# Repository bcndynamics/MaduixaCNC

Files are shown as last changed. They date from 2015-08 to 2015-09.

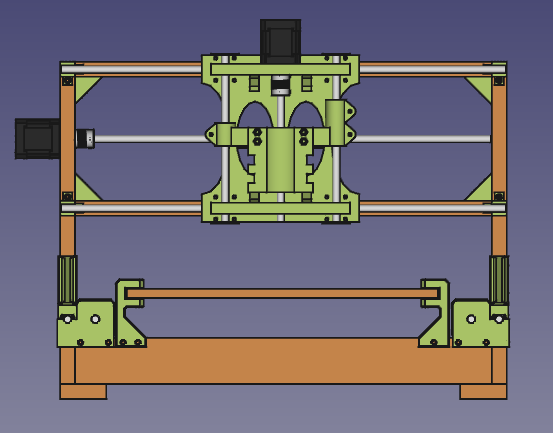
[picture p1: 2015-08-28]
03.Pictures/MaduixaCNC-front-r.png

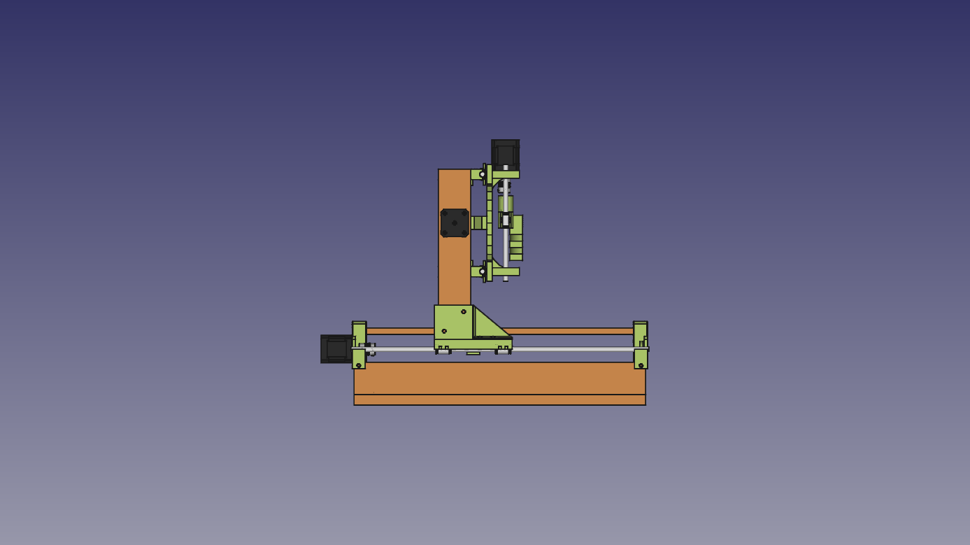
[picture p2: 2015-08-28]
03.Pictures/MaduixaCNC-left.png

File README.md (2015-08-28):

MaduixaCNC is an open source technology project developed by BCN Dynamics. It is a kit to do it yourself a CNC milling machine of 3 axis.

Components are the more accessible and affordable as possible. With accessible we mean that the components should be easy to find anywhere in the world. So, MaduixaCNC uses DM wood for the base structure and frame, 3dprintable plastic parts, and some common hardware stuff such as screws, nuts, bars, and so on. It uses NEMA17 motors and Arduino electronics.

MaduixaCNC is a CNC machine for milling, machining, drilling, PCB milling/routing, drawing and cutting, among others. Many things can be automatically produced with a CNC machine. MaduixaCNC is ready to use many possible tools, you just need to configure it your way.

It has a universal holder to use any tool. So you can plug a drill, a dremel, a cutter, a laser, a pen or whatever you need.

It is open source, published under GPL v3.0. So anyone can reproduce it wherever in the world without patents problems. Moreover, anyone can participate by providing improvements, changes or derivates. We are waiting for your improvements!

More information at BCN Dynamics website:
http://bcndynamics.com/en/product/kit-maduixa-cnc
http://bcndynamics.com

Spanish and Catalan information:
http://bcndynamics.com/es/MaduixaCNC
http://bcndynamics.com/ca/MaduixaCNC

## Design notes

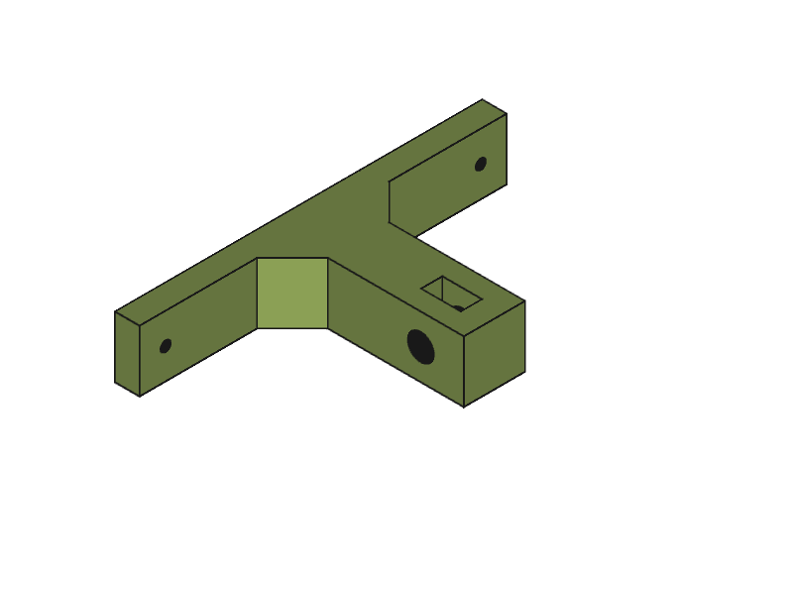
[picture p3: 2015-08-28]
03.Pictures/x-drive-train-CNC.png

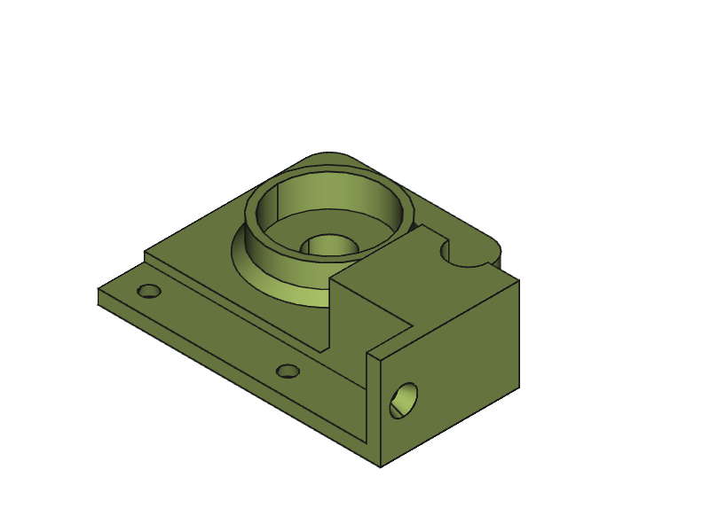
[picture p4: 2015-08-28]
03.Pictures/y-end-idler-CNC-left.png

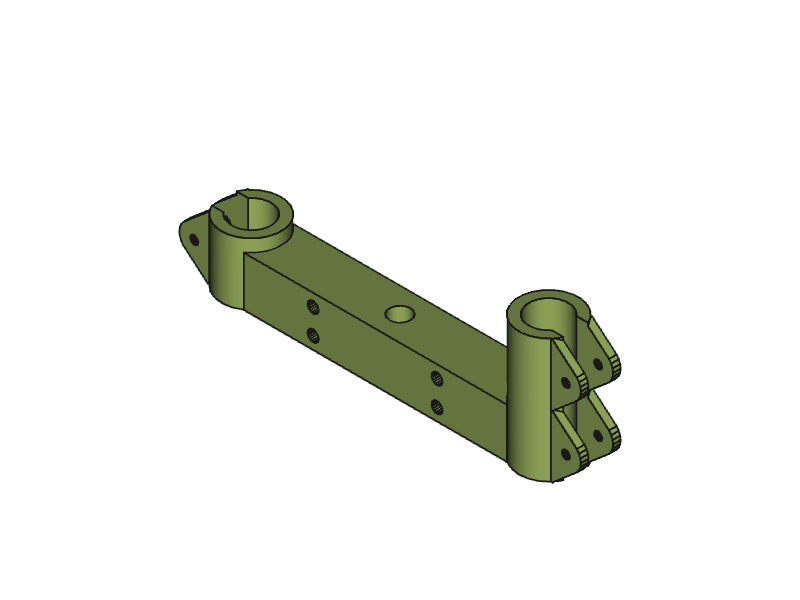
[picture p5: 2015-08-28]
03.Pictures/z-carriage-CNC.png

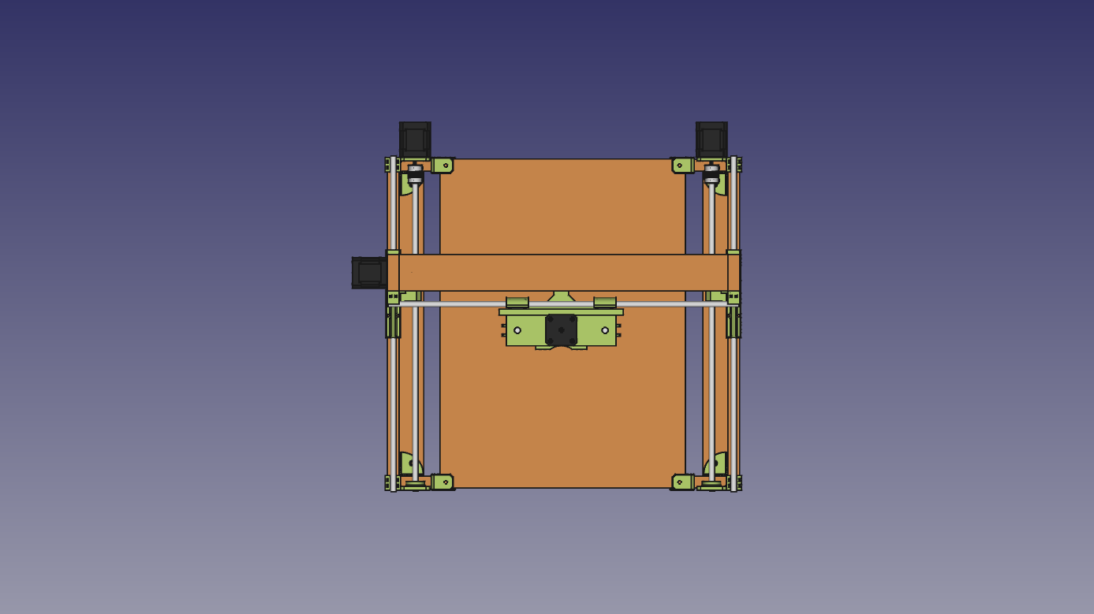
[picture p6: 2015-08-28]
03.Pictures/MaduixaCNC-top.png

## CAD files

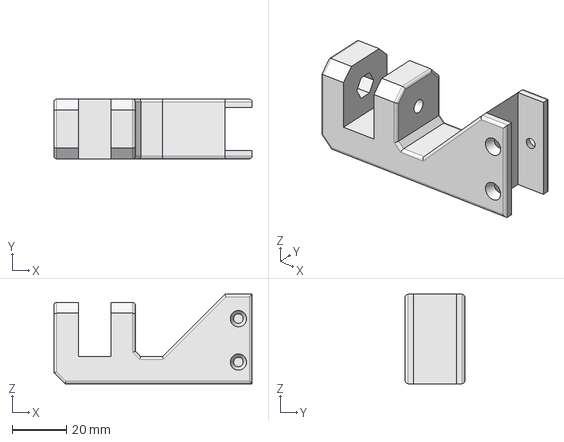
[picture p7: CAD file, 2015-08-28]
01.Sources/bed-holder-CNC.fcstd
73.0 x 22.0 x 33.0 mm

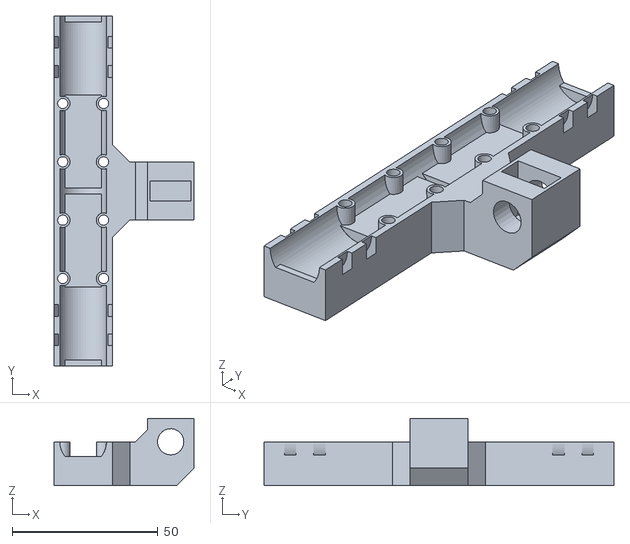
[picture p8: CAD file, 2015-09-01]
02.STLs/y-carriage-CNC.stl
48.0 x 120.0 x 23.0

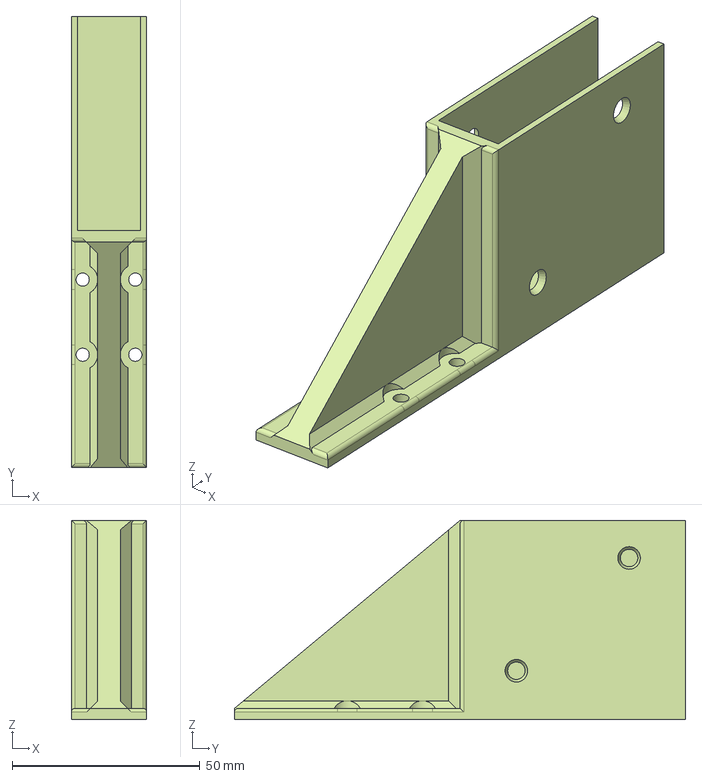
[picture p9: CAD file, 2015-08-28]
01.Sources/y-triangles.fcstd
20.0 x 120.0 x 53.0 mm

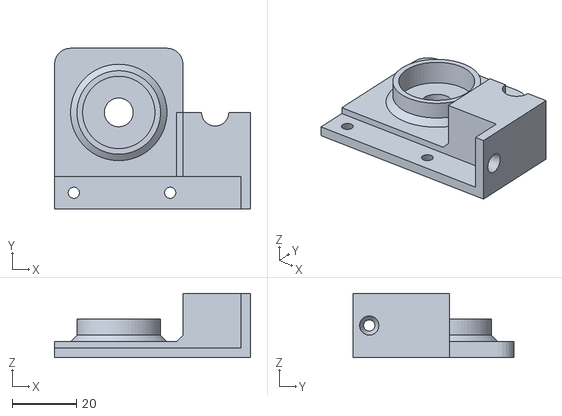
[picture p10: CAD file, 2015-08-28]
02.STLs/y-end-idler-CNC-right.stl
61.0 x 50.0 x 20.0

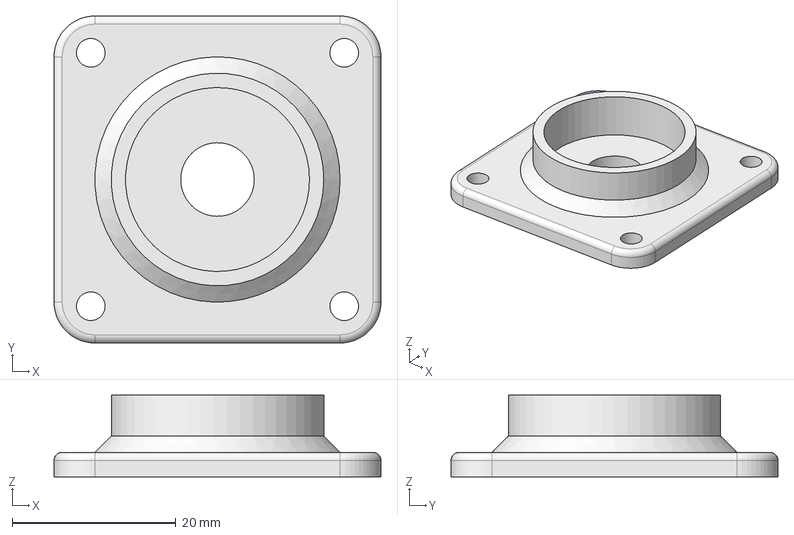
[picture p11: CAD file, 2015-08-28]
01.Sources/x-end-idler-CNC.fcstd
40.0 x 40.0 x 10.0 mm

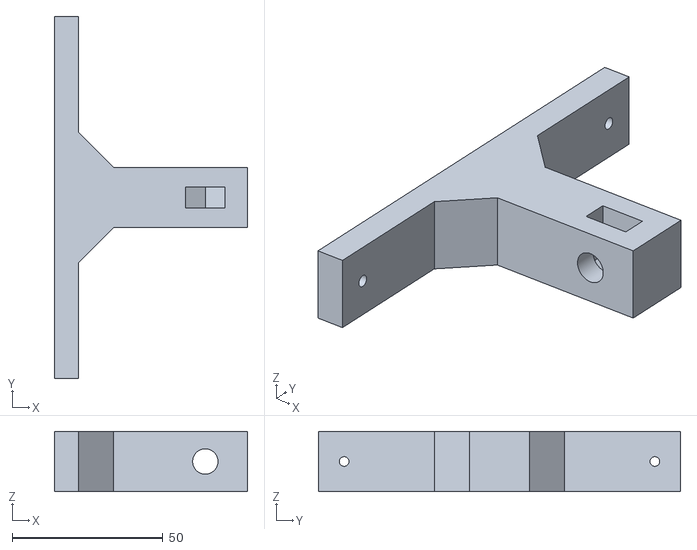
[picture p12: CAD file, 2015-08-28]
02.STLs/x-drive-train-CNC.stl
64.0 x 120.0 x 20.0

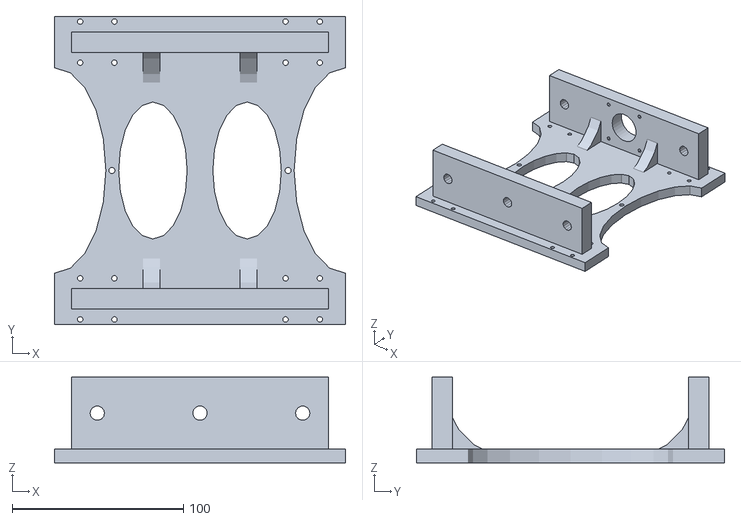
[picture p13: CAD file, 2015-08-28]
02.STLs/x-carriage-CNC.stl
170.0 x 180.0 x 50.0

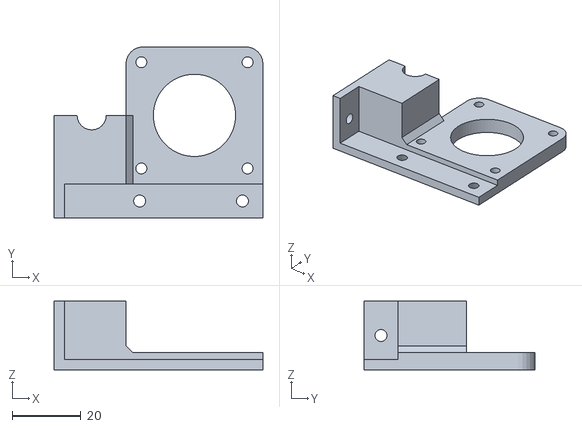
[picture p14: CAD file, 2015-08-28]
02.STLs/y-end-motor-CNC-right.stl
61.0 x 50.0 x 20.0

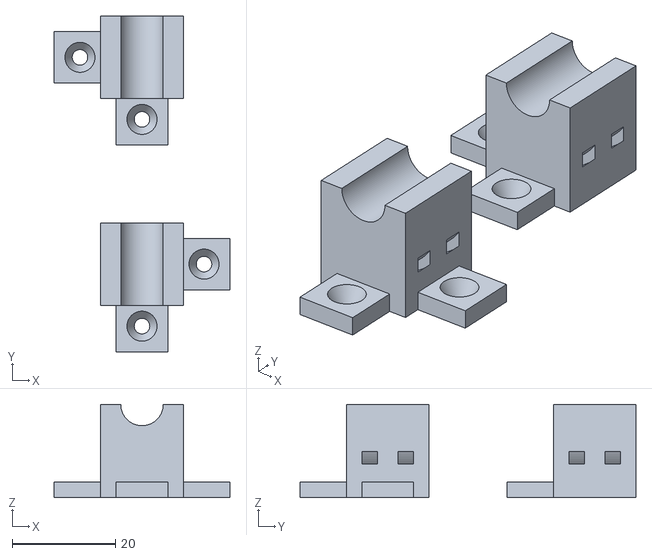
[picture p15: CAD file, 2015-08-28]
02.STLs/x-corner-CNC-AB.stl
34.0 x 65.0 x 18.0

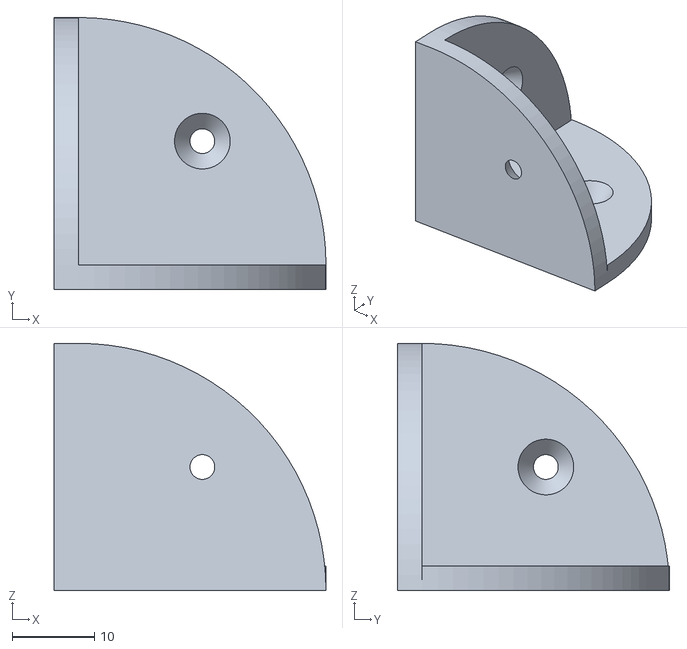
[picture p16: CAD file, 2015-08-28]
02.STLs/3sides-corner-CNC.stl
33.0 x 33.0 x 30.0

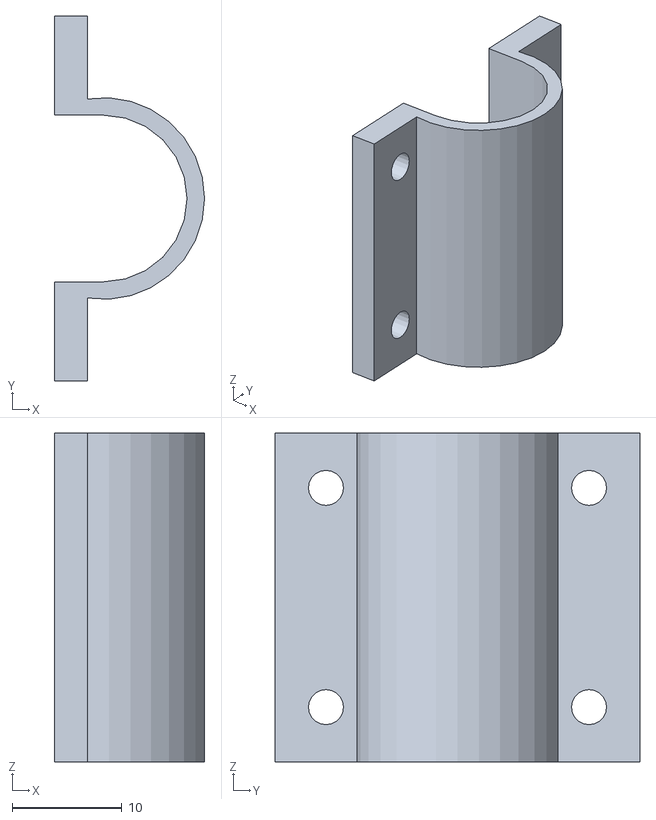
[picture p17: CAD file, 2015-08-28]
02.STLs/lm8uu-holder-CNC.stl
13.7 x 33.3 x 30.0

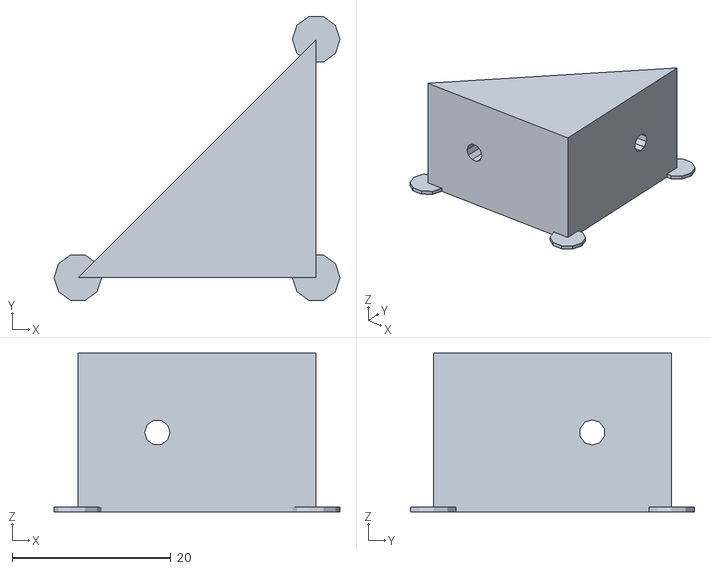
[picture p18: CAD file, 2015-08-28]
02.STLs/2sides-corner-CNC.stl
36.0 x 35.7 x 20.0

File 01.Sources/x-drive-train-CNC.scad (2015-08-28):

///////////////////////////////////////////////////////////////////////////////
//                                                                           //
//                       MaduixaCNC - BCN Dynamics                           //
//                                                                           //
///////////////////////////////////////////////////////////////////////////////
//
// File: x-drive-train-CNC.scad
//
// Authors: Dani Díaz <dani@bcndynamics.com>,
//          Victor Sapena <victor@bcndynamics.com>,
//          Emili Sapena <emili@bcndynamics.com>
//
// Copyright (c) 2015 by the original authors.
//
// This file is part of MaduixaCNC.
// 
// MaduixaCNC is free: you can redistribute it and/or modify
// it under the terms of the GNU General Public License as published by
// the Free Software Foundation, either version 3 of the License, or
// (at your option) any later version.
// 
// MaduixaCNC is distributed in the hope that it will be useful,
// but WITHOUT ANY WARRANTY; without even the implied warranty of
// MERCHANTABILITY or FITNESS FOR A PARTICULAR PURPOSE.  See the
// GNU General Public License for more details.
// 
// You should have received a copy of the GNU General Public License
// along with MaduixaCNC.  If not, see <http://www.gnu.org/licenses/>.
//
// http://bcndynamics.com 
///////////////////////////////////////////////////////////////////////////////

///////////////////////////////////////////////////////////////////////////////
// Variables

aresta=20;
llarg=60;
distancia_forats=103;
canto_llarg=120;
gruix_agarre=8;

///////////////////////////////////////////////////////////////////////////////
// Main

difference(){
  union(){
    translate([llarg/2,0,0])
      cube([llarg,aresta,aresta],center=true);
      
    cube([gruix_agarre,canto_llarg,aresta],center=true);
  }

  translate([0,distancia_forats/2,0])
    rotate([0,90,0])
      cylinder(r=1.6,h=50,$fn=100,center=true);

  translate([0,-distancia_forats/2,0])
    rotate([0,90,0])
      cylinder(r=1.6,h=50,$fn=100,center=true);

  translate([46,0,0])
    rotate([90,0,0])
      cylinder(r=4.2,h=50,$fn=100,center=true);

  translate([46,0,9])
    rotate([90,90,0])
      hull(){
	cylinder(r=7.5,h=7,$fn=6,center=true);
	
	translate([10,0,0])
	  cylinder(r=7.5,h=7,$fn=6,center=true);
     }
}   

hull(){
  translate([20,0,0])
    cylinder(r=4,h=20,$fn=20,center=true);
    
  translate([0,20,0])
    cylinder(r=4,h=20,$fn=20,center=true);
    
  translate([0,-20,0])
    cylinder(r=4,h=20,$fn=20,center=true);

}

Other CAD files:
01.Sources/y-axis.fcstd
02.STLs/y-end-idler-CNC-left.stl
02.STLs/y-triangle-CNC.stl
02.STLs/y-end-motor-CNC-left.stl
02.STLs/bed-holder-CNC.stl
02.STLs/x-end-idler-CNC.stl
01.Sources/2sides-corner-CNC.scad
01.Sources/3sides-corner-CNC.scad
01.Sources/universal-holder-CNC.scad
01.Sources/x-carriage-CNC.scad
01.Sources/x-corner-CNC-AB.scad
01.Sources/z-carriage-CNC.scad
02.STLs/universal-holder-CNC.stl
02.STLs/z-carriage-CNC.stl

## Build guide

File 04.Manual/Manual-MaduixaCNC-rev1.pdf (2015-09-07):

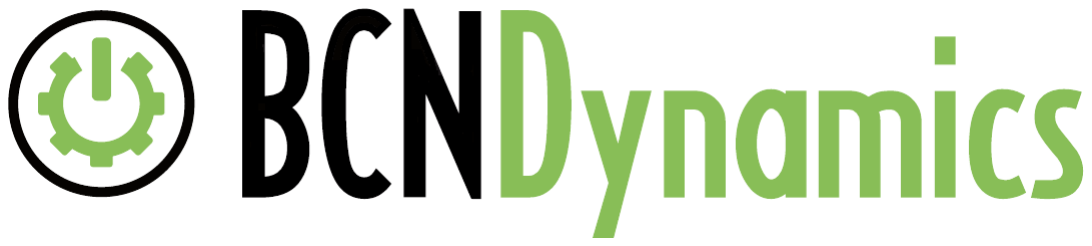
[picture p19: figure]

## MaduixaCNC

## Manual de montaje

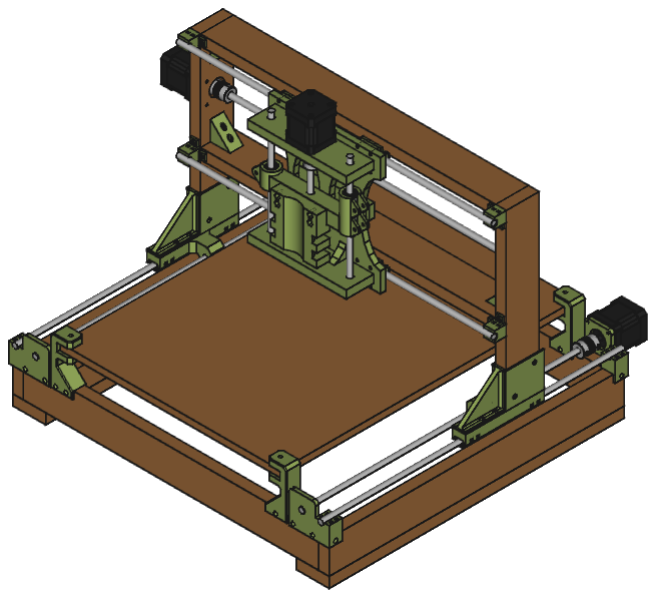
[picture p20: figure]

Versión del documento: | 1.0.3
Fecha última revisión: | 07/09/2015
Autores: | Victor Sapena, Daniel Díaz, Emili Sapena
Licencia: | Creative Commons CC Attribution-Noncommercial-Share Alike 3.0 Unported (http://creativecommons.org/licenses/by-nc-sa/3.0/)
http://bcndynamics.com · info@bcndynamics.com · 93 165 85 80 | @bcndynamics

Disclaimer – Descarga de responsabilidades. Por favor, lea atentamente.

Los manuales u otros documentos informativos publicados por BCN Dynamics (en adelante, Manuales) se ofrecen con ánimo de ayudar a los usuarios y pueden servirles de guía para realizar sus proyectos. BCN Dynamics publica los Manuales bajo licencia libre y los ofrece gratuitamente a sus usuarios/clientes.

BCN Dynamics no se hace responsable del uso que se haga de sus Manuales, y no garantiza la idoneidad, fiabilidad, especificidad, precisión y exactitud de la información facilitada. En ningún caso la información publicada en los Manuales puede servir para reclamaciones o devoluciones de productos vendidos en la tienda de BCN Dynamics.

Dado que los Manuales estan publicados bajo licencia libre y se ofrecen gratuitamente, se subministrarán “tal cual” (“as is”), sin garantía de ningún tipo, ni expresa ni tácita, incluídas las garantías implícitas a su comercialización, adecuación para un uso específico y lícito, aún sin quedar limitado a éllas, salvo pacto en contrario realizado previamente por escrito.

Las fotos, imágenes, figuras, esquemas, tablas u otros componentes gráficos incluídos en los Manuales pueden no corresponder con los componentes que el cliente haya adquirido.

Al comprar algún producto en BCN Dynamics que incluya un manual o documento informativo usted acepta que en ningún caso la información facilitada puede usarla en contra de BCN Dynamics, para reclamaciones, devoluciones ni indemnizaciones.

Las garantías de los productos que comercializa BCN Dynamics puede encontrarlas en la siguiente URL: http://bcndynamics.com/es/tienda/garantias

## 1. MaduixaCNC. Introducción

MaduixaCNC es un proyecto de tecnología libre de fresadora con control numérico por computadora (CNC) de 3 ejes. El nombre proviene de la traducción al catalán de la palabra fresa, la fruta. Se trata de un proyecto de kit con instrucciones de montaje que utiliza los componentes más accesibles posibles. La estructura se construye con placas de madera DM, tornillos para madera y piezas de plástico imprimibles en 3D. El resto de componentes son de ferretería (varillas, tornillos, tuercas...), motores paso a paso NEMA17 y electrónica basada en Arduino, muy parecida a la eletrónica usada para las impresoras 3D, pero más sencilla, ya que no es necesario controlar temperaturas ni extrusión.
La fresadora CNC MaduixaCNC puede, entre otros, fresar, mecanizar, taladrar, dibujar y cortar. La herramienta de mano (dremel, normalmente) no se incluye en el proyecto (ni en los kits) ya que la herramienta a utilizar dependerá de cada uno y de lo que quiera conseguir con la máquina. La disparidad de herramientas dremel y sus distintos precios y utilidades hace que no sea conveniente ligar la máquina CNC a una herramienta concreta. Por eso, la MaduixaCNC incluye un soporte universal para herramienta.
En este manual se especifica la lista de materiales, y se explica como realizar el montaje físico de la máquina. El proyecto completo, además de los materiales del kit y este manual, incluye también el código fuente de los diseños de las piezas imprimibles en 3D, así como el firmware modificado para CNC de 3 dimensiones. El diseño de la MaduixaCNC, los diseños 3D en OpenSCAD y FreeCAD de las piezas imprimibles en 3D, así como el diseño FreeCAD de la visualización completa de la máquina, se han realizado íntegramente en el departamento de I+D de BCN Dynamics. El proyecto MaduixaCNC es libre, y se publica bajo licencia GPL v3.0. El proyecto está inspirado en la fresadora CNC de José Salatino¹
, que basa su
estructura en varillas metálicas y piezas impresas en 3D. Después de trabajar conjuntamente con J. Salatino durante varias sesiones, el equipo de BCN Dynamics decidió empezar un proyecto nuevo desde cero basado en maderas y con diseños de piezas distintos para facilitar su montaje. El equipo de I+D de BCN Dynamics quiere agradecer públicamente a Jose Salatino su ayuda y generosidad. ¡Todos los inventores de proyectos libres son bienvenidos en BCN Dynamics!
1. https://grabcad.com/library/cnc-modular-machine-1

## 2. Lista de materiales

### 2.1. Piezas de plástico imprimibles en 3D

2sides-corner-CNC x4 | 3sides-corner-CNC x4 | Bed-holder-CNC x4
Lm8uu-holder-CNC x4 | Universal-holder-CNC x1 | X-carriage-CNC x1
X-corner-CNC-A x2 | X-corner-CNC-B x2 | X-drive-train-CNC x1
X-end-idler-CNC x1 | Y-carriage-CNC x2 | Y-end-idler-CNC-left x1

Y-end-idler-CNC-right x1 | Y-end-motor-CNC-left x1 | Y-end-motor-CNC-right x1
Y-triangle-CNC x2 | Z-carriage-CNC x1

### 2.2. Resto de materiales

- Maderas
- 8 x Placa madera DM 450x50x16mm
- 2 x Placa madera DM 260x50x16mm
- Varillas
- 2 x Varilla lisa M8x460mm (mejor INOX)
- 2 x Varilla lisa M8x480mm (mejor INOX)
- 2 x Varilla lisa M8x180mm (mejor INOX)
- 3 x Varilla roscada M8x435mm
- 1 x Varilla roscada M8x140mm
- Tornillería
- 75 x Tornillo madera M3x16 DIN7505A
- 25 x Tornillo madera M3x25 DIN7505A
- 10 x Tornillo M3x10
- 24 x Tornillo M3x16
- 9 x Tornillo M3x20
- 8 x Tornillo M3x25

- 33 x Tuerca M3
- 64 x Arandela M3
- 8 x Tornillo M4x20
- 4 x Tornillo M4x40
- 12 x Tuerca M4
- 4 x Arandela M4
- 2 x Abrazadera sinfin 70-90 W2
- 4 x Abrazadera Manguera 8mm
- Bridas
- Mecánica
- 4 x Motor PaP NEMA17
- 3 x Acoplador flexible 5mm-8mm
- 1 x Acoplador rígido 5mm-M8
- 11 x Rodamiento lineal LM8UU
- 3 x Rodamiento axial 608zz
- Electrónica
- 1 x Arduino Mega 2560
- 1 x RAMPs v1.4
- 3 x Driver motor pap DRV8825 stepstick
- 1 x Cable USB 2.0 AM/BM 1.8m
- 1 x Fuente alimentación 12V
- 1 x Ventilador 40x40x10mm 12v
- Cables varios

## 3. Montaje

Antes de empezar lo mejor es visualizar la máquina que vamos a montar. En las siguientes imágenes se puede ver la MaduixaCNC desde todos los lados. Así cuando nos refiramos a la parte izquierda, derecha, frontal, trasera, superior o inferior sabremos a qué lado nos referimos.
El eje Y es el que mueve toda la estructura vertical adelante y atrás. El eje X mueve el carro de izquierda a derecha y el eje Z es el vertical, el que tiene menos recorrido, ya que sólo mueve la herramienta arriba y abajo.
Frontal | Trasera
Izquierda | Derecha
Superior | Inferior

### 3.1. Base

La base es el marco rectangular (casi cuadrado) de madera que aguantará la máquina entera y serivrá para montar el eje Y.

Paso 1

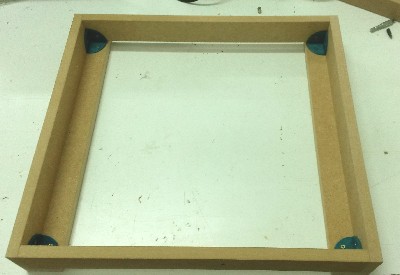
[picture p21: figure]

– Juntaremos dos maderas DM de 450x50x16mm por el lado de 450mm con 3 tornillos m3x25.
– Repetiremos el proceso para otras dos maderas de la misma forma.
– Con esto obtendremos dos conjuntos de dos planchas de madera, que si las miramos de perfil se ven como una "L".

Paso 2

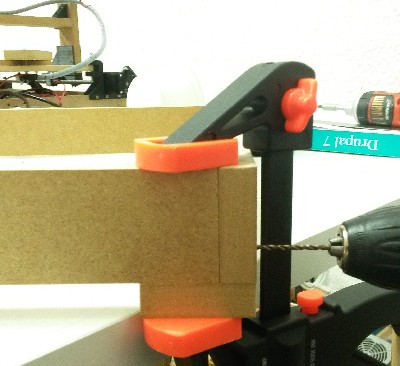
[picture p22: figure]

– En una de las dos "L", uniremos otra madera DM de 450x50x16mm. Esta debe ir encajada en la esquina que forman las dos maderas (ver foto).
– Para unirla usaremos dos tornillos m3x25.
– Repetimos el proceso para el otro conjunto de dos maderas, aunque teniendo en cuenta de no ponerlo en el mismo lado, ya que los dos conjuntos tienen que formar un rectángulo después.

Si todo ha ido bien, deberíamos tener esto:

NOTA: Tened en cuenta que las maderas no forman un cuadrado, sinó un rectángulo de 450x482mm!

Paso 3

– En cada esquina interna de la base de madera, colocaremos una pieza 3sides-corner-CNC, que sujetaremos contra las maderas con tres tornillos m3x16.
CONSEJO: Para atornillar las piezas de plástico a la madera, lo mejor es seguir estos 3 pasos: 1) colocar la pieza y entonces marcar con rotulador o lapiz los puntos donde irán los tornillos; 2) retirar la pieza de plástico y usar taladro o dremel para hacer un orificio fino de unos 2mm de diámetro; 3) colocar de nuevo la pieza, colocar la punta del tornillo en el orificio ya hecho y entonces atornillar con fuerza para terminar de hacer el agujero.

BASE TERMINADA

### 3.2. Eje Y

El eje Y se montará por encima de la base, por los lados cortos, tal como se ve en la imagen:

Eje y montado. Visto desde la parte trasera de la máquina.

Paso 1

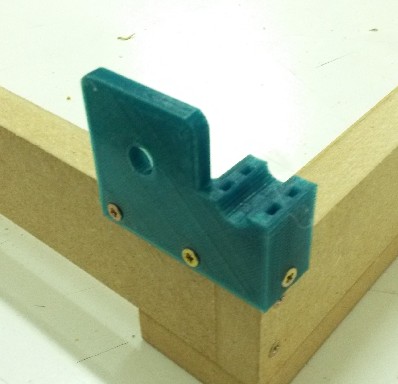
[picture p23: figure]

– Pondremos los y-ends en los dos lados de 482mm de la base de madera, orientados de tal modo que la parte más larga de la pieza impresa quede a lo largo de esa madera. En las dos esquinas de un lado pondremos los y-end-motor-CNC, mientras que en el otro lado pondremos los y-end-idler-CNC.

Paso 2

– Introducimos los rodamientos axiales B608zz en los alojamientos de los y-end-idler-CNC.

Si lo hemos montado todo bien, en estos momentos la estructura debería ser así:

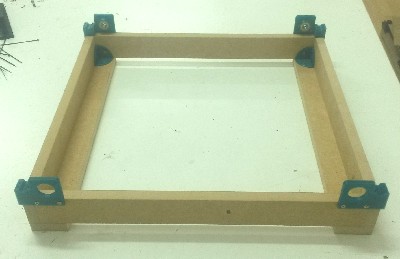
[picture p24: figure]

Paso 3

– Introducimos dos rodamientos lineales LM8UU en la varilla lisa M8x460mm.

– Encajamos los dos rodamientos lineales en la pieza impresa y-carriage-CNC. Luego los sujetamos contra la pieza usando dos bridas en cada rodamiento (4 en total).
– Ponemos una tuerca M8 en la ranura del y-carriage-CNC.
– Repetiremos el proceso con otros dos rodamientos lineales, la otra varilla M8x460, una de las tuercas M8 y el segundo y-carriage.

Paso 4

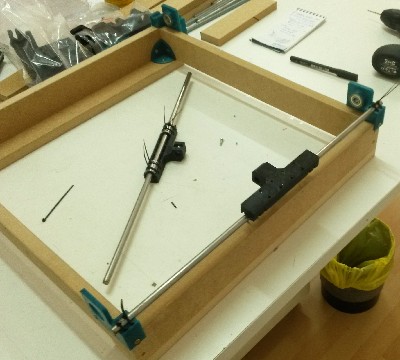
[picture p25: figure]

– Apoyaremos la varilla lisa en los y-end, un extremo en el idler y otro en el motor, y lo fijaremos con dos bridas en cada lado (4 en total).
– Repetimos el proceso para la otra varilla.

Paso 5

– Con 4 tornillos m3x10 uniremos uno de los motores Nema17 en la pieza impresa y-endmotor-CNC.
– Intentad dejar el conector del motor orientado hacia el interior de la estructura, facilitará luego hacer las conexiones del cableado.
– Repetimos el proceso con otro motor en el otro y-end-motor-CNC.

Paso 6

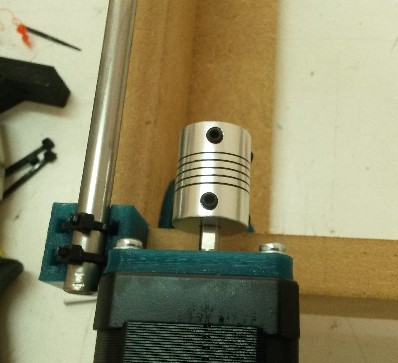
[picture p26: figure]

– Introducimos un acoplador flexible de 5-8 en el eje de uno de los motores, intentad que el eje del motor quede más o menos a la mitad de la longitud del acoplador. Apretamos los prisioneros del acoplador para sujetarlo, uno de los prisioneros debe ir posicionado para presionar en la parte plana del eje del motor.
– Repetimos el proceso para el otro motor con otro acoplador.

Paso 7

– Introducimos una varilla roscada M8x430mm por dentro del agujero del y-end-idler-CNC, la pasamos un poco y la roscamos en la tuerca que hemos puesto en el y-carriage-CNC. Damos unas cuantas vueltas hasta que la varilla sobresalga por el otro lado de la tuerca.
– Deslizamos la varilla hasta el acoplador que hemos puesto en el motor en el paso anterior, y la introducimos hasta que haga contacto con el eje del motor. Entonces apretamos los prisioneros para que la varilla ya no se salga.

Si todo lo hemos montado bien, deberíamos tener esto:

### 3.3. Eje X

El eje X desplazará el carro x, junto con el eje Z y la herramienta de izquierda a derecha. En la imagen se ve el eje X sin el eje Z montado:

Paso 1

– Unimos una de las maderas DM de 260x50x16mm (la que NO tiene el agujero para el motor) con otra de 450x50x16 de forma perpendicular, a 10cm de uno de los extremos de la madera de 260mm. Usamos dos tornillos de madera m3x25.

Paso 2

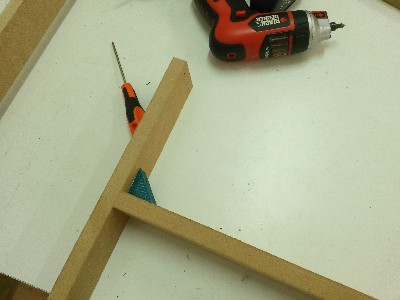
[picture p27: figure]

– Ponemos uno de los esquineros encajado en la esquina interna que forman las dos maderas, y lo apretamos contra ellas con dos tornillos de madera m3x16.

Paso 3

– Atornillamos la pieza impresa x-end-idler-CNC en la madera de 260mm, a 5cm de la madera que hemos atornillado. Usamos 4 tornillos de madera m3x16.
– Introducimos un rodamiento axial B608 en la pieza x-end-idler-CNC.

Paso 4

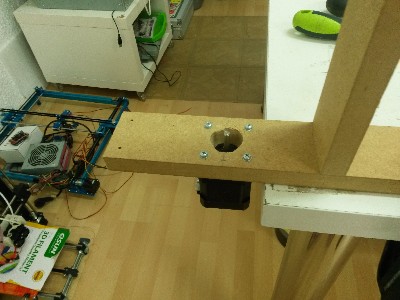
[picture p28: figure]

– En el otro lado de la madera de 450mm atornillamos la madera de 260mm restante, que tiene los agujeros para el motor, con dos tornillos de madera m3x16. Debemos ponerla también a 10cm.
NOTA: En la imagen anteiror se ve el motor, pero es mejor no ponerlo todavía. En las siguientes imagenes también se verá, aunque es sólo para que tengáis claro de que lado hablamos en cada momento.

Paso 5

– En la última madera de 450x50x16mm que tenemos, atornillamos dos esquineros, uno en cada lado. Usando un tornillo m3x16 en cada uno. Intentad que os queden justo en el extremo, ya que luego deberemos atornillarlos en las maderas de 260mm, y tiene que quedar bien alineado.

Paso 6

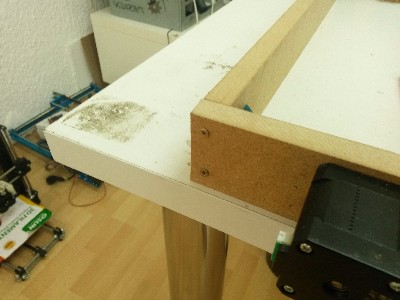
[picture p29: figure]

– Encajamos la madera de 450mm entre las dos de 260mm, y la fijamos con dos tornillos de madera m3x16 en cada lado (4 en total).
– Usamos también dos tornillos de madera m3x16 para acabar de fijar los esquineros.

Paso 7

– En las esquinas que forman las maderas de 450mm con las de 260mm, pondremos las 4 piezas impresas x-corner-CNC-A y x-corner-CNC-B. Una en cada esquina.
– Usaremos dos tornillos m3x16 en cada una de ellas para sujetarlas a las maderas.
NOTA: Si no os han quedado del todo bien puestas las maderas, este es el momento para rectificar. La separación entre las varillas lisas que pondremos a continuación debe ser de 15cm. Así que podéis jugar un poco con la posición de estos esquineros para garantizar que os queda todo recto.

Paso 8

– Pondremos una tuerca M8 en la ranura de la pieza impresa x-drive-train-CNC.

Paso 9

– Con el motor por separado, le pondremos el acoplador flexible de 5-8 hasta que el eje del motor quede por la mitad de la longitud del acoplador. Del mismo modo que lo hemos hecho con los acopladores del eje Y. Apretaremos bien los prisioneros, usando uno de ellos en la parte plana del eje del motor.
– Introduciremos la varilla roscada M8x430 en el acoplador, hasta que toque contra el eje del motor. Apretaremos bien los prisioneros para fijar su posición.
– Introduciremos la varilla por el agujero para el motor de la madera de 260mm. Roscaremos la varilla en la tuerca que hemos atrapado en la pieza impresa x-drive-train-CNC. Daremos unas quantas vueltas para que la varilla sobresalga por el otro lado de la tuerca y deslizaremos todo el conjunto hasta hacer reposar el extremo libre de la varilla en la pieza impresa "bearing-holder-CNC", dentro del rodamiento axial.
– En el extremo donde tenemos el motor, este debería haber quedado arrán de la madera. Usaremos 4 tornillos m3x20 con 4 arandelas para sujetar el motor a la madera, usando los agujeros especialmente posicionados.

Paso 10

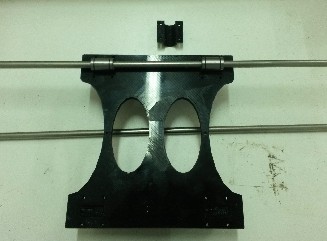
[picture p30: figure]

– En cada una de las dos varillas M8x480, introducimos dos rodamientos lineales LM8UU.
– Situamos la varilla encima de la pieza impresa x-carriage-CNC, de tal manera que los rodamientos lineales queden introducidos en las ranuras especialmente diseñadas.
– Usamos las 4 piezas impresas lm8uu-holder-CNC y 4 tornillos m3x20, con 4 tuercas y 8 arandelas m3 en cada una de ellas, para fijar la posición de los rodamientos, atornillándolas en la pieza de plastico.

Paso 11

– Apoyamos los extremos de las varillas sobre las x-corner-CNC, y con dos bridas en cada una de ellas fijamos las varillas sobre las piezas impresas.
– Usamos dos tornillos m3x20, junto con dos
tuercas y dos arandelas m3, para unir las
piezas impresas x-drive-train-CNC y x-carriage-CNC.

NOTA: Es un buen momento para comprobar que, al girar la varilla roscada de las X, el conjunto se desliza con facilidad de extremo a extremo.

Paso 12

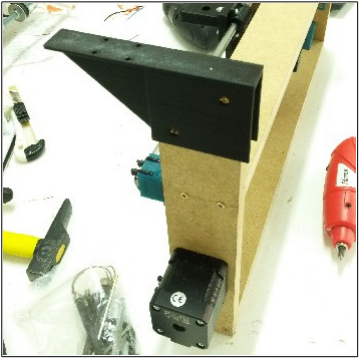
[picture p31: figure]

– En los extremos libres de las maderas de 260mm, introduciremos los triangulos de soporte del eje X (pieza impresa). (En la imagen se ve el eje Z del revés, visto desde abajo)
– Intentad que los triangulos queden bien ajustados a la madera. Ya que sinó podemos tener problemas con las alturas de cada lado.
– Usamos 4 tornillos de madera m3x16 en cada pieza impresa para fijarlas a la madera.

HEMOS TERMINADO EL EJE X

### 3.4. Eje Z

El eje Z desplaza verticalmente la herramienta, o mejor dicho, el soporte universal para herramientas. El recorrido del eje Z es mas corto que el X y el Y ya que en la mayoría de los casos el fresado no requiere un gran desplazamiento vertical.

Paso 1

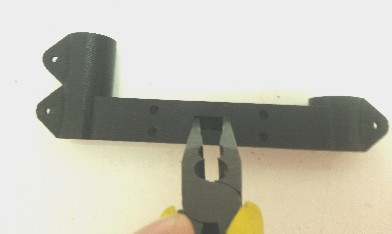
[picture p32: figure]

– Quitamos el soporte para la impresión de la pieza dentro de la ranura lateral del zcarriage-CNC.

Paso 2

– Introducimos una tuerca de M8 en la ranura lateral del z-carriage-CNC.

Paso 3

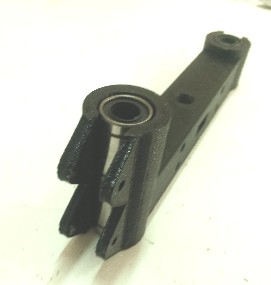
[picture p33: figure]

– Introducimos 3 rodamientos lineales LM8UU, dos en un lateral y uno en el otro.
– Los introducimos deslizándolos desde arriba. Por el momento no usamos tornillos, intentad que al manipular la pieza no se desplazen demasiado.

Paso 4

– Ponemos una abrazadera metálica en uno de los extremos de una de las varillas lisas M8x180mm, la apretamos fuerte para que no se deslice.
– Hacemos lo mismo con la otra.

Paso 5

– Introducimos una de las varillas lisas de M8x180mm por uno de los agujeros del x-carriage-CNC. La pasamos por el rodamiento lineal puesto anteriormente en la pieza zcarriage-CNC, y seguimos hasta atravesar el agujero del otro extremo del x-carriage-CNC.
– Hacemos lo mismo con la otra varilla, pasándola por los dos rodamientos lineales del otro lateral y llegando al otro agujero del x-carriage-CNC.
– Ponemos abrazaderas metálicas en los extremos que sobresalen de las varillas lisas y apretamos.

Paso 6

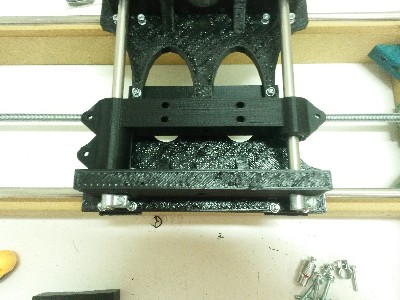
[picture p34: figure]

– Usamos 3 tornillos de m3x20 con 3 tuercas y 6 arandelas m3 para fijar la posición de los rodamientos lineales, en los agujeros hechos en el z-carriage-CNC.

Paso 7

– Introducimos 4 tuercas M4 en los alojamientos hexagonales del universal-holder-CNC.

Paso 8

– Con 4 tornillos y 4 arandelas, unimos el z-carriage-CNC con el universal-holder-CNC.
– Los tornillos los tendremos que apretar desde detrás del x-carriage-CNC.

Paso 9

– Situamos el motor en el alojamiento del X-carriage-CNC. Usamos 4 tornillos m3x16 y 4 arandelas para fijar su posición.

Paso 10.

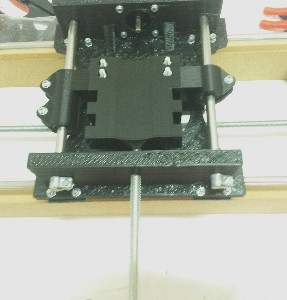
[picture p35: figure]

– Introducimos la varilla roscada M8x140 por el agujero central inferior del X-carriage-CNC. La deslizamos hasta llegar a la tuerca del z-carriage-CNC y la roscamos hasta que sobresalga una parte por arriba.

Paso 11.

– Usamos el acoplador rígido de 5-8, y 4 tornillos m3x6 para unir el eje del motor con la varilla roscada m8x180. Usad uno de los tornillos en la parte plana del eje del motor.

EL EJE Z ESTÁ TERMINADO

3.5. Unión de los ejes.
Hemos montado los ejes X y Z por un lado, y eje Y por el otro. A continuación vamos a unirlos.

Paso 1

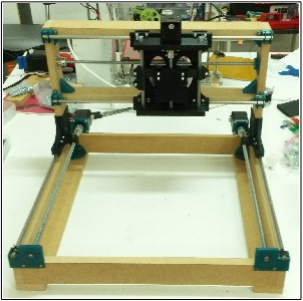
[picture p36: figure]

– En primer lugar, nos aseguraremos de que los y-carriage-CNC estén alineados. La mejor forma es rotar la varilla roscada de cada lado manualmente hasta que el y-carriage-CNC esté en contacto con el y-end-motor-CNC.
– Una vez los dos y-carriage-CNC estén alineados, situaremos la estructura del eje X encima, haciendo que cohincidan los agujeros de la base de los triángulos con los de los y-carriage-CNC.

Paso 2

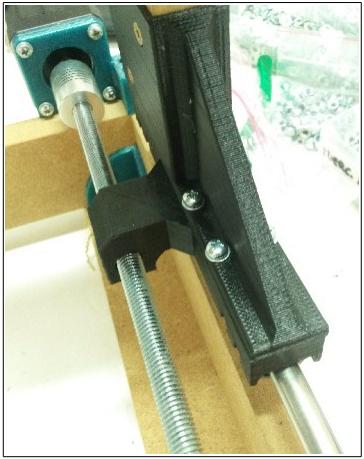
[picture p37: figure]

– Usamos 4 tornillos m3x25, 4 tuercas y 8 arandelas m3 para unir cada triángulo con el y-carriage-CNC.

YA HEMOS UNIDO LOS EJES.

### 3.6. Electrónica

El montaje de la parte mecánica ya está listo. Ahora falta colocar la electrónica y tendremos la máquina montada.

Paso 1

– Aprovechando que el marco es de madera, podemos sujetar la electrónica en la base. Usamos 3 tornillos de madera m3x16.

Paso 2

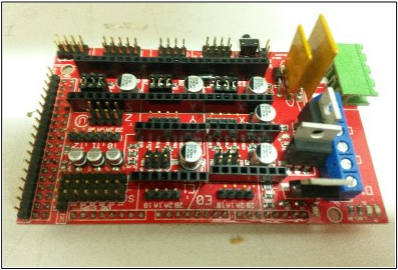
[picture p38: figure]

– En la ramps v1.4 que viene en el kit, ponemos 3 jumpers en los pins que hay debajo de las ranuras para los drivers de motor del eje X, Y y Z. ( usaremos 3 en total)

Paso 3

– Conectamos los drivers de motor. La única forma de saber seguro que los estamos conectando bien, es fijarse en los nombres que tienen los pins del driver y de la ramps. Sencillamente deben cohincidir.
– Usamos el pegamento para disipadores para pegar los disipadores encíma del microchip de los drivers de motor. El disipador no debe entrar en contacto con las patas de los drivers. – La cola puede tardar un buen rato en secarse, así que mejor esperaremos unas horas para conectar la ramps a la arduino y poner el resto del cableado.
– Una vez la cola de los disipadores esté seca, conectaremos la ramps a la placa arduino.

NOTA: Las RAMPs suelen tener los espacios para drivers con etiquetas indicando qué eje son. En las impresoras 3D (la RAMPs suele usarse para impresoras 3D), el eje Z es el que suele tener 2 motores que se mueven por igual, y por eso hay dos conexiones para motor en el eje Z. En el caso de la MaduixaCNC, se usan dos motores en el eje Y en lugar de en el Z. Así que habrá que connectar los motores del eje Y en las ranuras donde indica Z y al revés, y luego en el firmware cambiar el pinaje de la placa.

Paso 4

– Conectamos los dos motores del eje Y, usamos un cable de 50cm para cada uno. Estos motores los conectaremos en cada una de las dos ranuras del eje Z de la ramps. Los dos orientados en el mismo sentido.

NOTA: Aunque se conecten al espacio propio del eje Z estos motores serán los del eje Y. El firmware que ofrecemos en el CD ya viene configurado de esta manera.

Paso 5

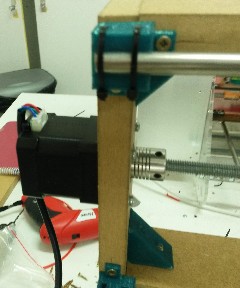
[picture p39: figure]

– Usaremos un cable de 100cm para el motor del eje X.

– Lo conectaremos en la ranura propia de su eje en la ramps.

Paso 6

– El último motor, el de las Z, lo conectaremos en la ranura del eje Y de la ramps.

Paso 7

– Con cuatro tornillos m3x16 y 4 tuercas, unimos los soportes del ventilador al ventilador de 40x40.
– Luego encajamos las patas de los soportes en la ramps, de manera que el ventilador refrijere los drivers.
– Conectamos el cable alargo de 2 hilos al extremo del cable del ventilador.
– Pelamos las puntas del cable de dos hilos sin conectores, y los conectamos a la ramps. El rojo en el "+" y el negro en el "-".

Paso 8

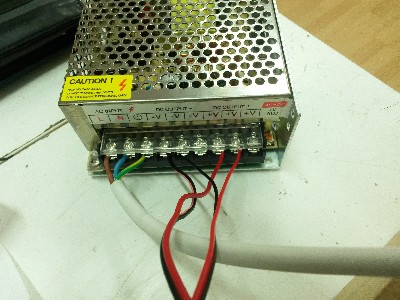
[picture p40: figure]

– Pelamos el otro extremo del cable de dos hilos sin conectores, y conectamos las puntas a la fuente. Cable rojo en una de las salidas positivas (+V) y cable negro en una de las negativas (-V).
– El conector que nos ha quedado libre en el alargo para el cable del ventilador, lo cortamos y pelamos un poco las puntas. Luego conectamos el cable rojo en otra salida positiva y el negro en una de las negativas.
– Conectamos el cablde de alimentación. El importante es el verde/amarillo, que debe ir conectado a la toma de tierra.
– Una vez realizadas las conexiones podemos buscar un alojamiento para la fuente. Nosotros la solemos poner clavada en el interior de la base, del revés, para que no le entre viruta de material.

### 3.7. Cama de trabajo

Paso 1

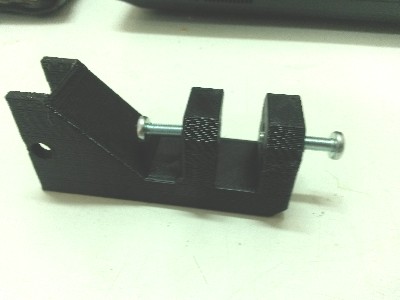
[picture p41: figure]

– En cada una de las 4 piezas impresas bed-holder-CNC, introducimos una tuerca en cada una de las ranuras interiores y roscamos dos tornillos M4x20, uno en cada lado.

Paso 2

– Colocamos los bed-holder-CNC en la parte interna de la base, justo al lado de los y-end.
– Usamos 3 tornillos para madera m3x16 para fijar la posición de cada soporte. (Comprobamos la distancia entre ellas usando la misma cama perforada antes de clavar)

Paso 3

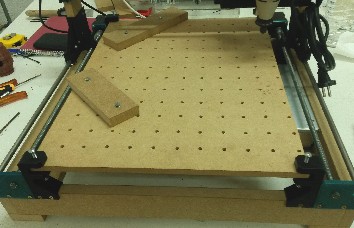
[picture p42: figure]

– Posamos la madera perforada por dentro de las ranuras de los soportes.
– Con los tornillos inferiores introducidos en los soportes nivelaremos la cama, mientras que con superiores apretaremos para fijar la posición.

Con esto habremos terminado el montaje de la MaduixaCNC Para hacerla funcionar necesitarás subir el firmware al arduino y utilizar algun sofware que envíe las instrucciones CNC (gcode) a la máquina. Encontrarás más información en la web de BCN Dynamics.

3.8. Opcional: Dremel.

Si queremos usar la CNC con una dremel, usaremos las dos bridas metálicas que vienen en el kit para fijar su posición en el adaptador universal.

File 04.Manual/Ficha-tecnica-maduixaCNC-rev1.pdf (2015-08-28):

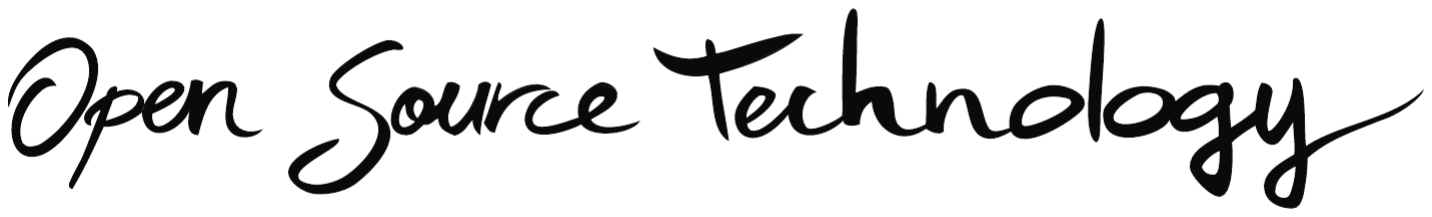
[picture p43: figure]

# Maduixa CNC

## Características técnicas:

- Dimensiones sin herramienta: 530x505x410mm.
- Volumen de trabajo: 275x260x45 mm.
- Aplicaciones: Grabado ( madera, cera, metacrilato, placa de circuito impreso),

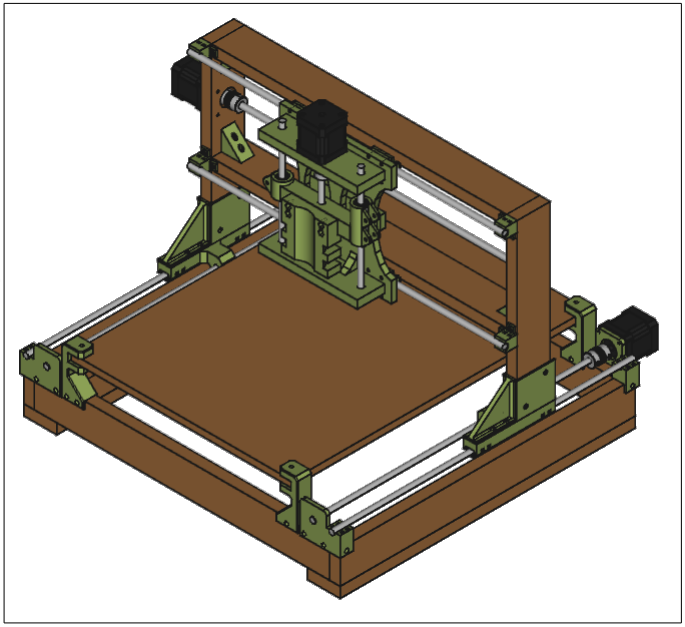
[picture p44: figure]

Fresado superficial, plotter, taladro, corte laser.
- Fuerza trabajo: Variable según herramienta.
- Velocidades:
- Desplazamiento XY: 200mm/min.
- Grabado: [50-100] mm/min.
- Fresado superficial: 50 mm/min.
- Taladro: 20 mm/min.
- Plotter: [100-200] mm/min.
- Alturas de capa: 0.1-0.3mm
- Estructura: Estructura de madera DM 16mm grosor. Piezas impresas en PLA. Rodamientos de bolas LM8UU en ejes X, Y, Z. Rodamientos final varilla B608. Acoplamientos flexibles en ejes X,Y y rígido en eje Z. Motores NEMA17.
- Electrónica: Arduino Mega 2560 + RAMPS 1.4 + drivers DRV8825 stepstick. Fuente de alimentación 220V AC, 12V 20A (240W). Ventilador 40x40mm para electrónica.
- Software: Firmware Marlin preconfigurado. Entorno recomendado: f-engrave + Pronterface. Archivos admitidos: DXF/GCODE. Sistemas operativos compatibles: Linux (recomentado), Windows XP y superiores, Mac OS X y superiores.
- Comunicaciones: Puerto USB tipo B.
- Documentación: CD con diseños de piezas impresas en ".stl", firmware y manual de montaje.
http://bcndynamics.com · info@bcndynamics.com · 93 165 85 80 | @bcndynamics

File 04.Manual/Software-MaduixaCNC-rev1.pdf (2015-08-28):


## MaduixaCNC

## Manual de Software y firmware

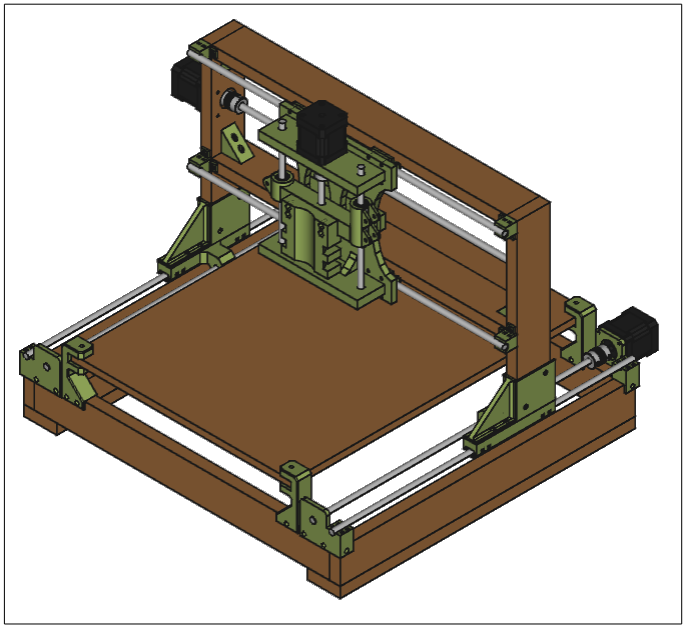
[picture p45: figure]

Versión del documento: | 1.0.1
Fecha última revisión: | 27/08/2015
Autores: | Victor Sapena, Daniel Díaz, Emili Sapena
Licencia: | Creative Commons CC Attribution-Noncommercial-Share Alike 3.0 Unported (http://creativecommons.org/licenses/by-nc-sa/3.0/)
http://bcndynamics.com · info@bcndynamics.com · 93 165 85 80 | @bcndynamics

Límite de responsabilidades. Por favor, lea atentamente.

Los manuales u otros documentos informativos publicados por BCN Dynamics (en adelante, Manuales) se ofrecen con ánimo de ayudar a los usuarios y pueden servirles de guía para realizar sus proyectos. BCN Dynamics publica los Manuales bajo licencia libre y los ofrece gratuitamente a sus usuarios/clientes.

BCN Dynamics no se hace responsable del uso que se haga de sus Manuales, y no garantiza la idoneidad, fiabilidad, especificidad, precisión y exactitud de la información facilitada. En ningún caso la información publicada en los Manuales puede servir para reclamaciones o devoluciones de productos vendidos en la tienda de BCN Dynamics.

Dado que los Manuales estan publicados bajo licencia libre y se ofrecen gratuitamente, se subministrarán “tal cual” (“as is”), sin garantía de ningún tipo, ni expresa ni tácita, incluídas las garantías implícitas a su comercialización, adecuación para un uso específico y lícito, aún sin quedar limitado a éllas, salvo pacto en contrario realizado previamente por escrito.

Las fotos, imágenes, figuras, esquemas, tablas u otros componentes gráficos incluídos en los Manuales pueden no corresponder con los componentes que el cliente haya adquirido.

Al comprar algún producto en BCN Dynamics que incluya un manual o documento informativo usted acepta que en ningún caso la información facilitada puede usarla en contra de BCN Dynamics, para reclamaciones, devoluciones ni indemnizaciones.

Las garantías de los productos que comercializa BCN Dynamics puede encontrarlas en la siguiente URL: http://bcndynamics.com/es/tienda/garantias

## 1. Software

El primer paso es instalar el programario necesario para que todo funcione. Todos los programas citados aquí, necesarios para usar la fresadora CNC, se pueden descargar de forma fácil y gratuita desde sus respectivas webs, en todas las plataformas. Además, todos son programas libres, de código abierto, con las ventajas que ello otorga.
Hemos probado decenas de programas para poder pasar de un formato vectorial, por ejemplo DXF, a un GCODE válido para el firmware que utlizaremos (Marlin modificado). Si bien para la impresión 3D lo tenemos solucionado: usamos slic3r para laminar (generar el GCODE) y luego pronterface para conectarnos con la màquina. Para la MaduixaCNC aún no tenemos un entorno completo. El tema está en que hay muchas formas de utilizar la CNC. No es lo mismo serigrafiar (seguir un camino) que, hacer un grabado a laser o, por ejemplo, taladrar o mecanizar. No sólo se pueden usar herramientas distintas, sinó que las instrucciones GCODE generadas dado un archivo vectorial, serán distintas en función de la herramienta y la broca utilizada.
Así que por el momento el entorno que estamos utilizando es F-Engrave + Pronterface, teniendo que hacer modificaciones en el GCODE generado por F-Engrave para que Pronterface y Marlin (el firmware) lo acepten. Estamos abiertos a sugerencias al respecto. Si conoces un software libre mejor, coméntalo en el foro de BCN Dynamics ;)

Arduino IDE:

Arduino IDE es el programa que usaremos para cargar el firmware a nuestra placa electrónica. Su instalación es imprescindible para que los sistemas operativos reconozcan la placa al conectarla al ordenador. Lo podeis descargar desde su web:
http://arduino.cc/en/pmwiki.php?n=main/software

Además, en la web encontrareis una guía para su instalación.

F-engrave

F-engrave es un programa para generar archivos ".gcode" de máquina CNC , orientado a trabajos de grabado, fresado superficial o plotter. Es un software sencillo e intuitivo que no nos costará mucho controlar.
http://www.scorchworks.com/Fengrave/fengrave.html

En la web, podréis encontrar enlaces para su descarga así como videos tutoriales para su funcionamiento.

Kliment/Printrun:

El pronterface es el programa de interfaz para las impresoras 3D, pero con unas pequeñas adaptaciones nos servirá para nuestra CNC. Nos permitirá mover sus ejes, situarla, determinar su posición, enviar código G-code a través de su consola, etc.. El programa os lo podeis descargar desde el siguiente enlace:
https://github.com/kliment/Printrun

## 2. Cargar el firmware

Antes de empezar, tenéis que saber que en el programa Arduino IDE existe la opción de buscar una palabra o frase en concreto (muy útil para encontrar una linea de código determinada).
La opción está en Edit ----> File... y escribímos el texto que queramos buscar.

Paso 1

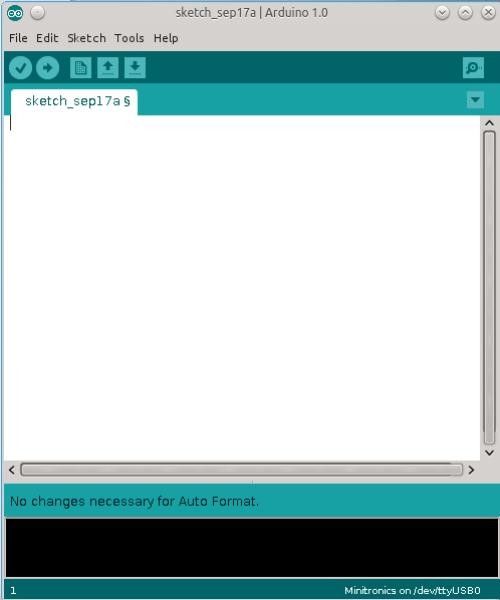
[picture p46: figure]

Arrancaremos el programa Arduino IDE.

Paso 2

- Seleccionamos nuestro tipo de placa en el menú: Tools ----> Board ---->
ArduinoMega2560 or
MegaADK. También
tenemos que seleccionar el puerto donde está
conectada, en el menú
Tools---->SerialPorts ,
aunque esto es algo que en principio el programa de
arduino ya detecta de forma automática(*), a no ser que tengamos más de una
arduino conectada al
ordenador.

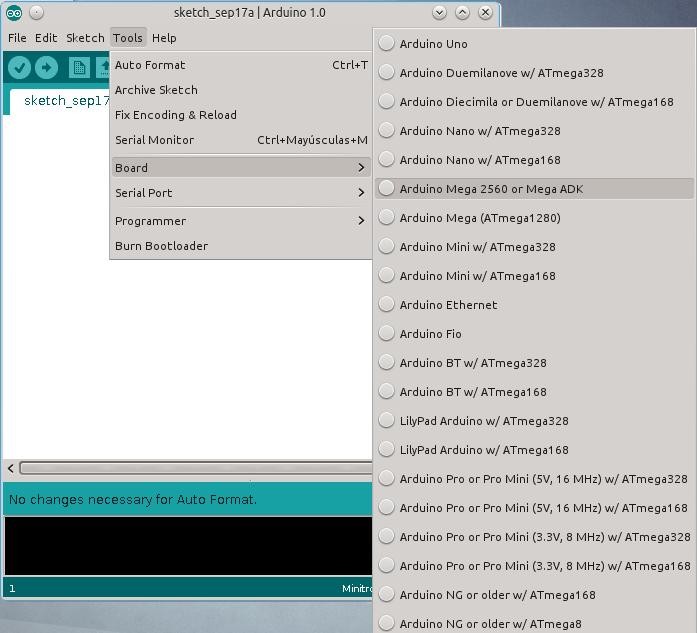
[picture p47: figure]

(*) Nota: Si el Arduino IDE no detecta una placa conectada, cuando esta sí lo está, revisad la instalación del programa, ya que lo más provable es que os falten drivers para vuestra versión de sistema operativo (es un problema típico en Windows). En dicho caso, consultad las guías de la página de Arduino para completar correctamente la instalación.

Paso 3

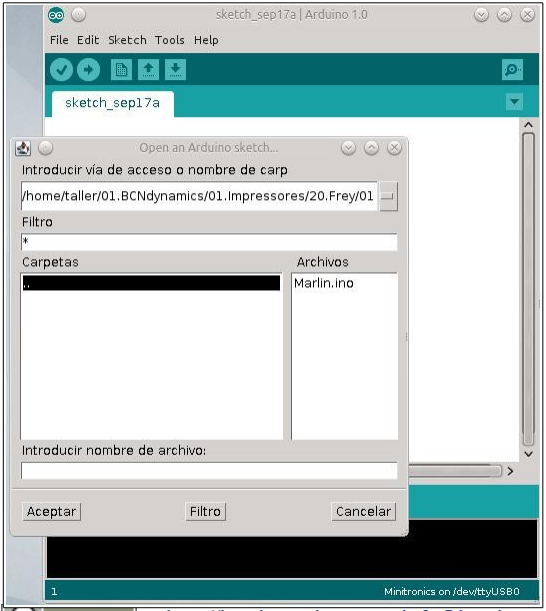
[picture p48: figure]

- Abrimos el archivo "marlin.ino", que en contraremos en la sección "Firmware" en el CD del kit.
- Para abrirlo usamos el menú: File ---> Open ---> ... y buscamos la carpeta donde tengamos el archivo.

Paso 4

– Apretamos el botón "Upload", que se presenta como una flecha en la parte superior derecha de Arduino IDE.
– Esperamos a que la cárga del firmware se complete.

## 3. Calibración

Antes de volver al mundo del software, tenemos que estar seguros de que físicamente todo está correcto. Para situar y usar la MaduixaCNC, utilizaremos el pronterface. Es un programa pensado para impresoras 3D, con lo cual habrá ciertas cosas del programa que no se ajustarán del todo, pero por lo que lo necesitamos nos irá bien.

Paso 1

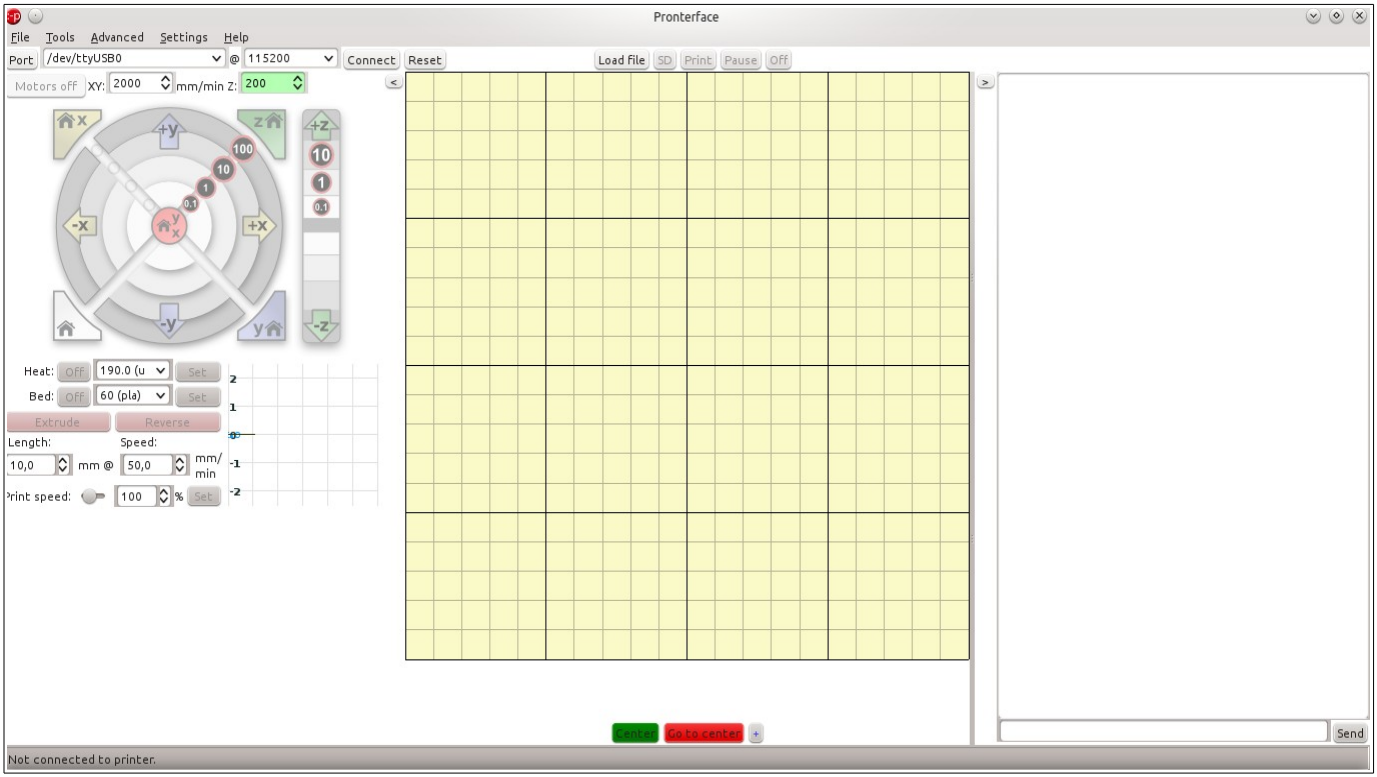
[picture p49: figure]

Arrancamos el pronterface:
- Seleccionamos el puerto USB correspondinete a nuestra fresadora en la opción de "Port".
- Seleccionamos la velocidad de conexión, 115200.
- Apretamos "Connect".

Cuando arranquemos, nos fijaremos que Pronterface nos da valores disparatados de la temperatura. Esto es por que hemos deshabilitado por firmware la lectura de este valor para adaptarlo a la CNC.

Paso 2

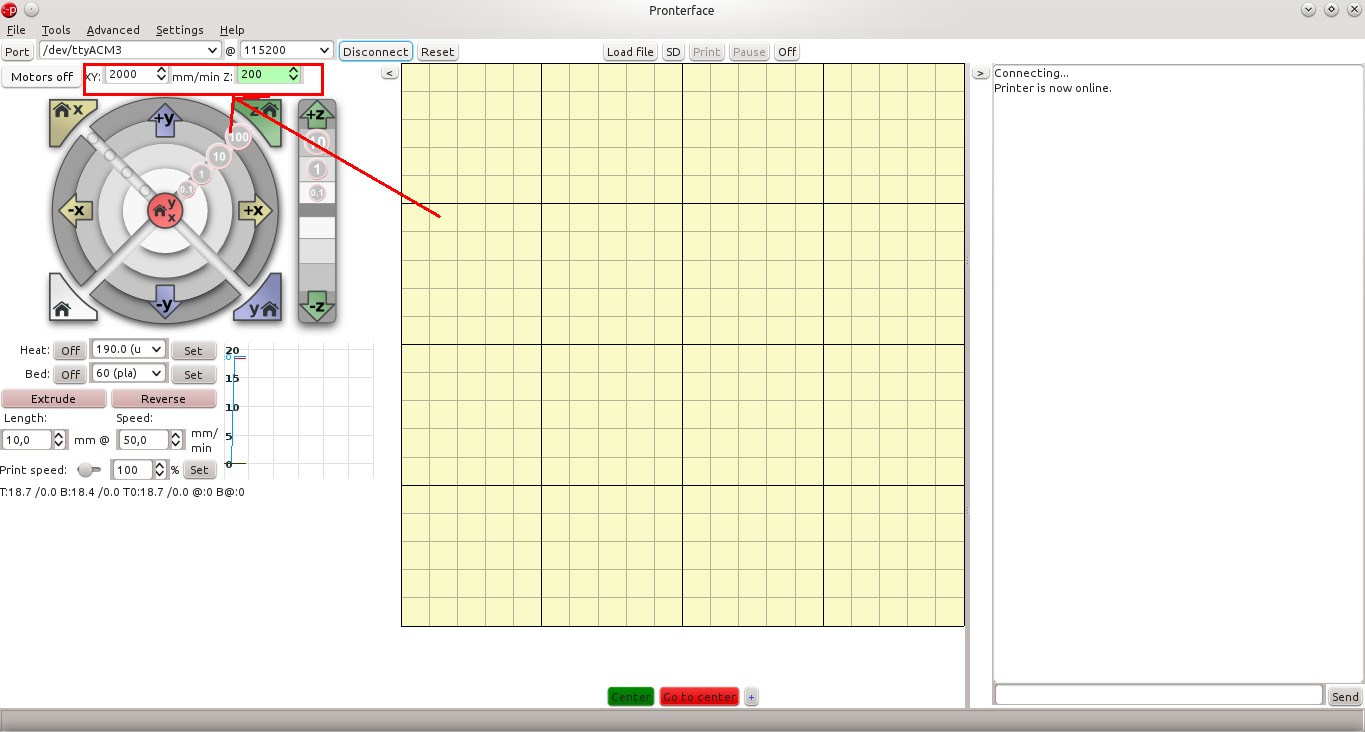
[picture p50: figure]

- En las velocidades de motor, pondremos 200 mm/min para X e Y, y 100 para la Z. Esto determina las velocidades a las que se moverán los motores de cada eje cuando lo hagámos nosotros mediante el programa, aunque no afectarán a la velocidad de trabajo, ya que esta se determina con el programa para generar el G-code.

Paso 3

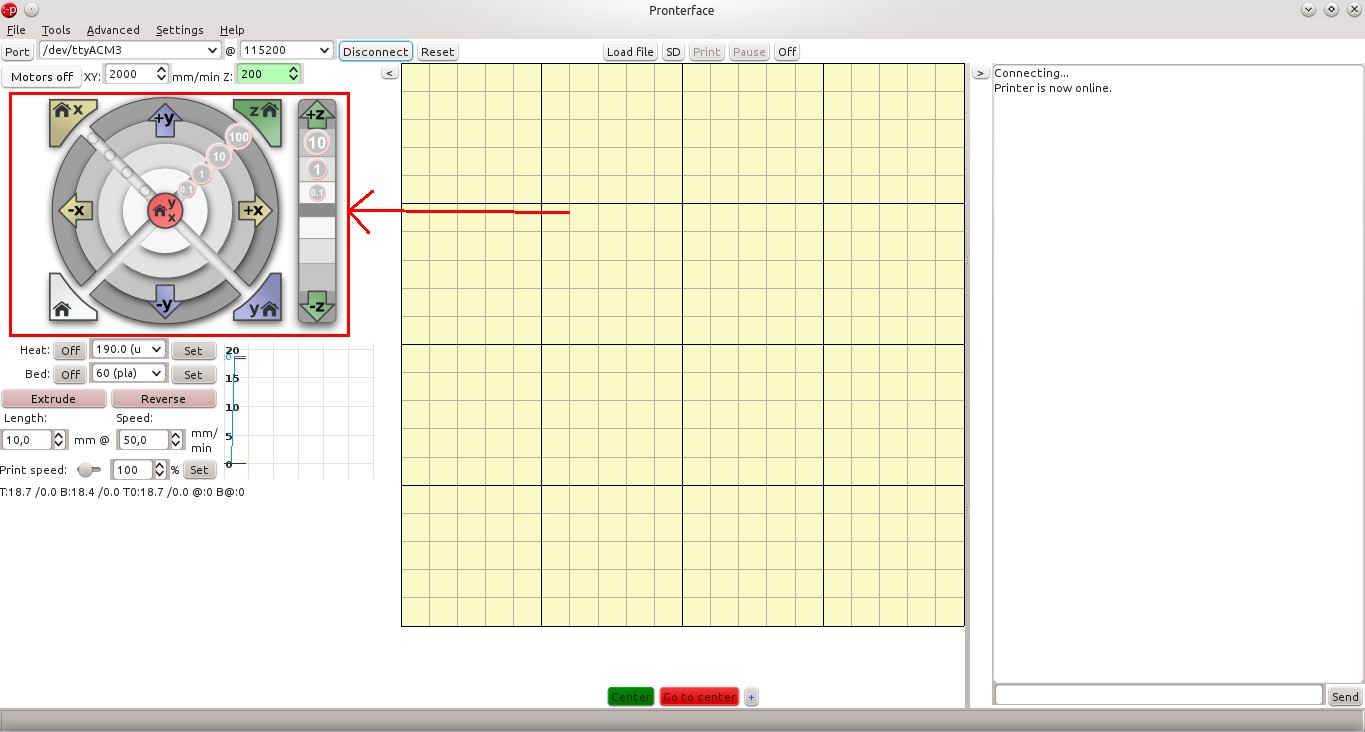
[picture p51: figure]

- Mediante el panel de control, provaremos de mover los motores de cada eje por separado. Da igual por cual empecéis. Los valores con un "-" deberían mover los ejes hacia el sentido del motor.
- Si al intentar mover el eje, este no se mueve y no sale ningún mensaje en la consola de Pronterface, probablemente el driver de ese eje no esté bien ajustado. Deberemos ajustar la poténcia de ese driver. Se hace mediante un pequeño tornillo que hay en cada driver al que llamaremos potenciómetro. Esto SIEMPRE DEBE HACERSE CON LA FUENTE DE ALIMENTACIÓN DESCONECTADA. Además, NUNCA GIRAREMOS EL POTENCIÓMETRO MÁS DE UN CUARTO DE VUELTA DE UNA SOLA VEZ.
- Si al provar de mover un eje, éste se mueve en sentido contrario a lo deseado, apretaremos el botón "motors off" del Pronterface, apagaremos la fuente, e invertiremos la conexión del cable del motor correspondiente en la electrónica, físicamente.
- Estos pasos deben hacerse para los ejes X, Y y Z.
- Tened en cuenta que en el eje Y se usan dos motores, así que necesitaréis más poténcia que en los ejes X y Z. Además, si tenéis que invertir el sentido de giro, procurad que los dos motores giren en la misma dirección!
- Si tenéis un tester, podéis usarlo para ajustar la poténcia de los drivers. La intensidad que pase por los drivers de cada eje debería estar en valores de entre 0.4-0.6A.

Si hemos podido mover todos los ejes, de momento hemos terminado con el Pronterface. Luego lo usaremos para cargar los "g.code" generados con F-engrave.

## 4.- Generar G-code con F-engrave

F-engrave es un programa que sirve para generar G-code para máquinas CNC. Con él podremos realizar los archivos para algunos de los trabajos que admite la MaduixaCNC como grabar texto o imagenes sobre superficies o hacer dibujos con un rotulador o bolígrafo. También podremos usarlo para hacer cortes de perfiles ya sean de madera o metacrilato.
Aun con esto, para poder abrir luego los archivos generados con el Pronterface, necesitarmos editar mínimamente los mismos para adaptarlos, aunque es un proceso sencillo.
En esta sección, a modo de ayuda, explicaremos como realizar trabajos de grabado con una Dremel.

Paso 1

Descargar e instalar F-engrave desde la página web, segun sus indicaciones. Está pensado para poderse ejecutar en las tres plataformas (Linux, Windows y MAC).

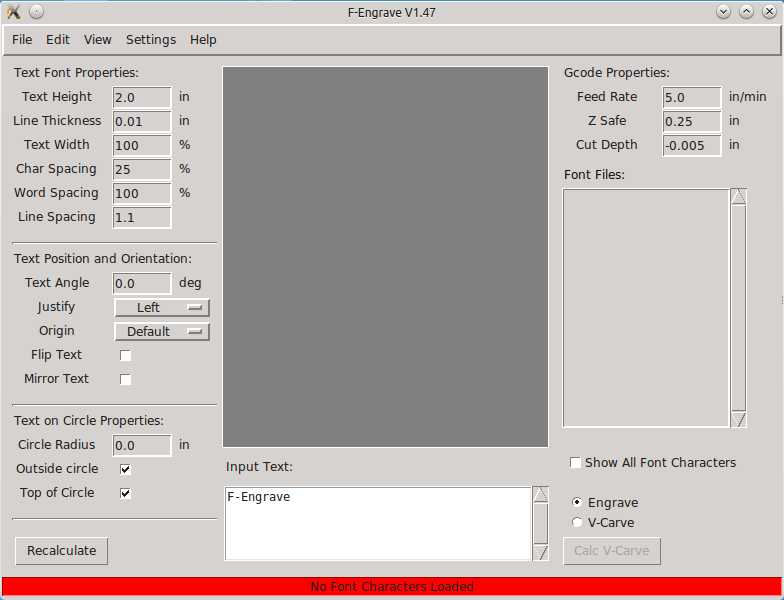
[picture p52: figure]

La pantalla inicial al abrirlo tendrá este aspecto.

Paso 2

- En "Settings ---> General Settings" cambiaremos las unidades. En la linea "Units" le indicaremos "mm" de milímetros en vez de "inch", pulgadas.
- Normalmente usaremos el trabajo "Engrave", pero si tenemos una punta cónica, podemos ir a "Settings---> V-Carve" y definir las propiedades de la punta. En todo caso, podemos realizar trabajos con la opción "Engrave" y una punta cónica sin problemas.
- En caso que no detecte las fuentes, deberemos indicarle el directorio donde están. Tendremos que ir a los menús:
1) "Settings ---> General Settings."
2) Nos dirigimos a "Fonts Directory" y apretamos en "Select dir".
3) Buscamos la carpeta con las fuentes. Por ejemplo, para Ubuntu estas se encuentran en: "/usr/share/fonts/truetype/.." y allí podemos elegir, en nuestro caso solemos usar la carpeta "./ttf-dejavu".

Paso 3

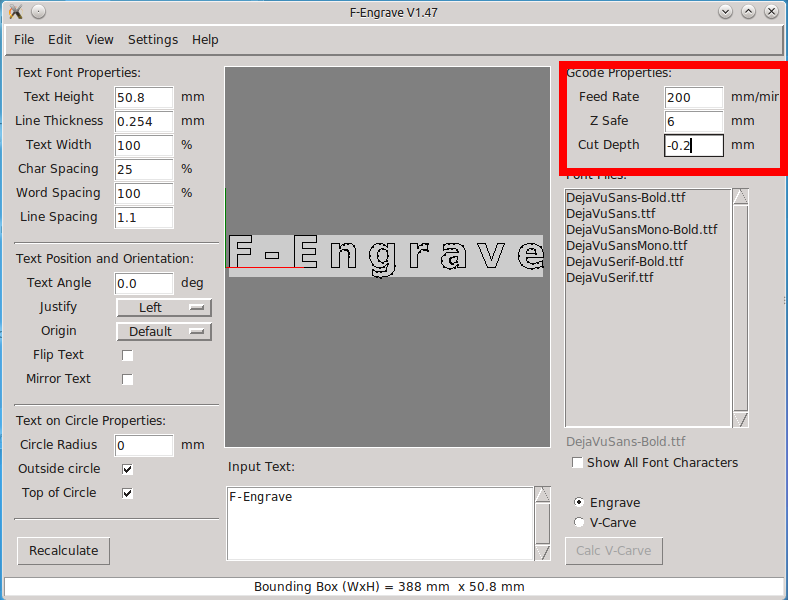
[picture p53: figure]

De nuevo en la pantalla principal del programa, modificaremos los valores de las propiedades del G-code, situadas en la esquina superior derecha de la ventana. Los valores aconsejables son: Feed Rate: [50,200] mm/minuto.
Dependiendo de la profundidad a la que queramos trabajar. Es la velocidad de trabajo. Os aconsejamos no aumentar este valor por encima de los 200mm/minuto si realizamos trabajos con una Dremel o taladro.
Z safe: [1-6] mm
Es la distancia a la que subirá el eje Z cuando viaje de un punto a otro sin realizar trabajo, con poner 1mm es suficiente.
Cut Depth: [-0.1,-0.3] mm
Es la profundidad de perforación a la que realizará el trabajo. Hemos de intentar no subir demasiado este valor, ya que empeorará el trabajo. Si queremos trabajos a mas profundidad, es preferible repetir el trabajo una vez terminado, bajando la herramienta manualmente a través del pronterface una vez terminada la primera vuelta. Sinó también podemos modificar el G-code, más adelante os explicaremos como.

Paso 4

A) Texto.
Si lo que queremos es grabar un texto sobre una superficie, ahora ya sólo tenemos que escribir el texto que queramos en el recuadro y apretar "recalculate".
Con las opciones de la izquierda de la pantalla principal, podremos modificar el grosor de las lineas, la separación entre palabras y/o letras, etc..
Una vez hecho todo esto iremos a "File---> Save as G-code.." y grabaremos el archivo g-code resultante.
B) Imagen ".DXF".

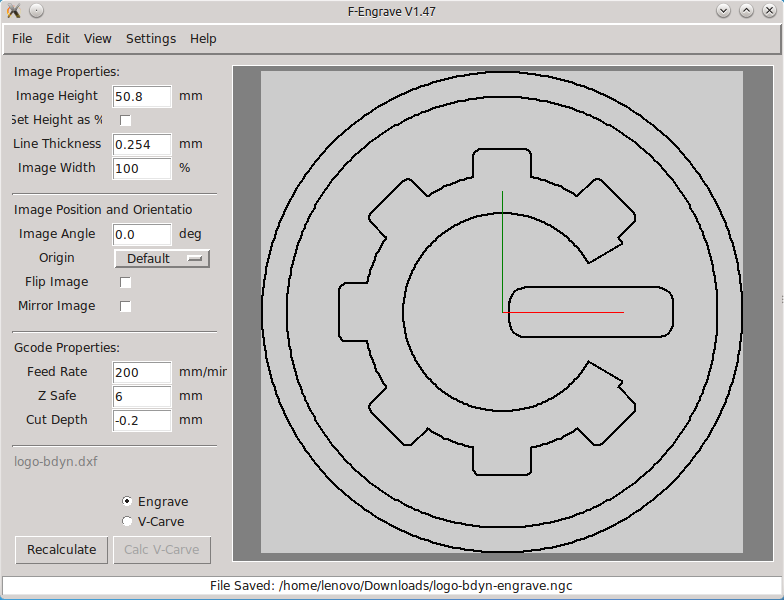
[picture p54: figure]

Si lo que queremos es hacer un grabado de un archivo ".dxf", iremos a "File---> Open DXF/Bitmap File"
Con los parámetros de la izquierda de la pantalla también podremos modificar el grosor de las lineas y el tamaño de la imagen.
Una vez hecho todo esto iremos a "File---> Save as G-code.." y grabaremos el archivo g-code resultante.

Paso 5

Para poder abrir el archivo generado con el Pronterface, tendremos que editarlo primero.

Abrimos el archivo con un bloc de notas o equivalente.

- Eliminamos todas las lineas entre parentesis del principio del archivo, hasta la linea (incluida) donde hay los corchetes "#".
- Eliminamos la linea con la instrucción "G91.1"
- Eliminamos la linea con las instrucciones "G17 G64 P0... "
- En la linea donde encontramos la instrucción "F " y el valor numérico, y eliminamos todo el contenido de la frase entre parentesis, con estos incluidos. Esto lo hacemos por que Pronterface no interpreta los paréntesis como comentarios, sólo el punto y coma.
En la imagen siguiente os mostramos en rojo lo que se tiene que eliminar.

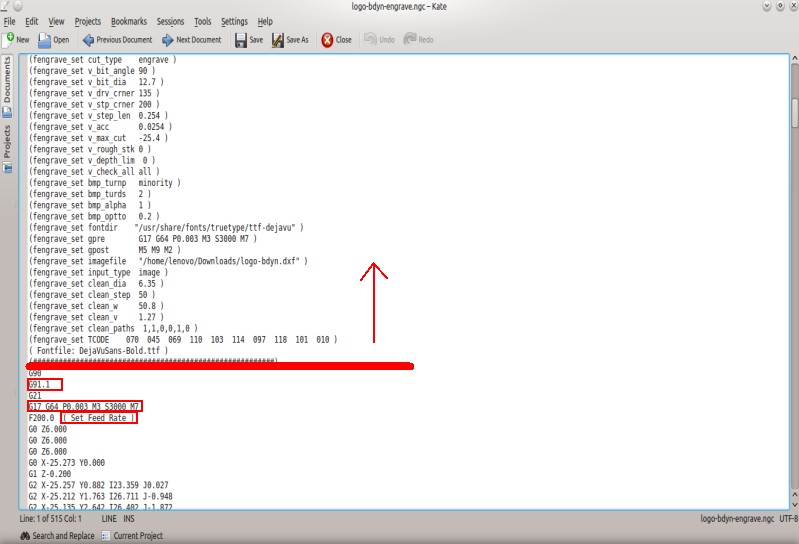
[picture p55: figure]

– Una vez tenemos las modificaciones realizadas,
vamos a guardar como y grabamos el archivo como "<nombredelarchivo>.gcode" . No lo dejéis como ".ngc" ya que pronterface no lo interpretará.

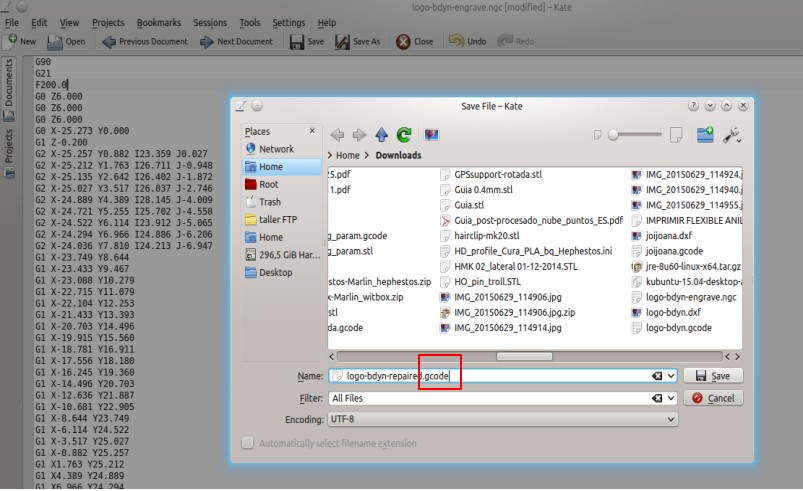
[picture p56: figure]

Paso 6

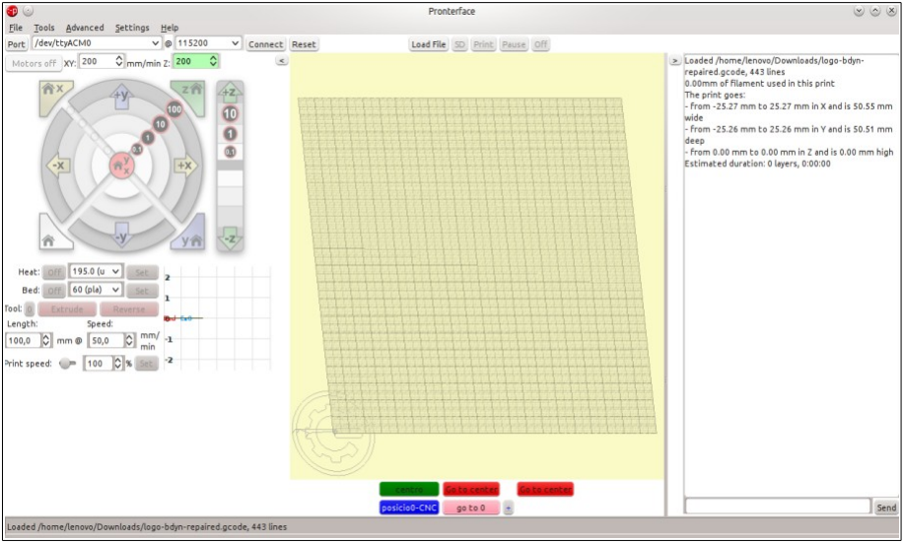
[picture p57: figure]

– Abrimos el Pronterface.
– Seleccionamos el puerto y la velocidad de conexión a 115200, apretamos "Connect".
– Abrimos el archivo con "Load file" y buscamos el directorio a través de las ventanas.
– Usando el panel de control de las X,Y y Z, situamos la punta de la dremel en el centro de la madera (u otro material) que queramos perforar, de manera que pasando un papel entre la superficie y la punta de la dremel rasque por los dos lados.
– Nos situamos en la consola de la derecha del pronterface y escribimos el código "G92 X0 Y0 Z0" para decirle a la MaduixaCNC que estamos en la posición [0,0,0] . Ya que si os fijáis en la imagen, el tiene en cuenta que el diseño está centrado en el origen de coordenadas.
– Una vez hecho todo esto, encendemos la Dremel y apretamos el botón "Print" del pronterface.
Si queremos que el grabado quede más marcado, tenemos un par de opciones.
Opcion 1:
– Iniciamos el trabajo apretando "Print".
– Esperaramos a que el proceso termine.
– En la consola de Pronterface escribimos: "G1 X0 Y0 Z0 F200" . Esto situará la impresora en el origen de coordenadar anterior. Con el control manual del Pronterface, bajamos la herramienta con el eje Z exáctamente la altura de capa de trabajo anterior.

– En la consola escribimos: "G1 X0 Y0 Z0" . Lo define como nuevo origen.
– Apretamos el botón "Print".
Opción 2:

– Buscamos el archivo .gcode editado y lo abrimos de nuevo con el bloc de notas.
– Seleccionamos todo el texto, excepto las dos primeras lineas, que contienen: "G90" y "G21" respectivamente.
– Copiamos todo el texto y lo pegamos justo al final del documento.
– Seleccionamos el fragmento que acabamos de copiar.
– Con la opción "buscar y reemplazar" , buscamos todos los comandos "Z-0.2" (Esto es si hemos hecho las capas a 0.2mm. Si generamos el archivo para capas de por ejemplo -0.3mm, deberemos buscar el comando Z-0.3) y los substituimos por "Z-0.4".
– Ahora podemos decidir si repetir el proceso, substituyendo ahora por Z-0.6, o guardamos el archivo. Y así sucesivamente aumentando el valor de 0.2 en 0.2 ( o con la capa que se desee). Como vas veces lo hagamos, más capas de 0.2mm realizará y más marcado quedará el grabado.
– Guardamos el archivo y lo abrimos con el Pronterface para realizar el trabajo de la manera habitual. La MaduixaCNC, al realizar la primera pasada, se situará en el origen sola y hará la siguiente, así sucesivamente hasta que haga todas las capas.

A fresar.

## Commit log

2015-08-28 First upload of the project
    [2sides-corner-CNC.scad, 2sides-corner-CNC.stl, 3sides-corner-CNC.scad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]
2015-09-01 adding y-carriage-CNC.stl file
    [y-carriage-CNC.stl]
2015-09-07 updated BOM in manual
